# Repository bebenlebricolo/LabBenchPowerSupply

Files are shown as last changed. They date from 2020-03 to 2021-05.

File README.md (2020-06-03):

# LabBenchPowerSupply
A Diy lab bench power supply, made as simple as possible, from an Arduino Nano and generic discrete parts

## Motivation(s)
### A complete design, built from the ground up, for everyone
The main goal of this project is indeed to build a bench power supply, but I really wanted to provide a complete project including all the electronical design, mechanical design and software design that goes with it.

### Keep it simple, and as cheap as possible!
#### The Electronical side of the force
This project is built around simple electronic devices/parts which we could find in almost any electronic store with a decent collection of parts. The parts were chosen with 2 main things in mind :
* **They need to be cheap !** If cheaper does not always correlates with better, cheap parts are often related to products that have been around for a long time and have demonstrated their capabilities more times than we can ever count them.
* **They need to fulfill their task without compromises** : the chosen parts shall largely fit the requirements of power, size, etc.. This is essentially a safety requirement, there is no usage for us here to size the parts so close to the requirements we don't have any error margin left.
* **They need to be available** almost everywhere, and not only restricted to some obscure parts of the world. If not, they need to have a compatible part we can rely on.
* **They need to be well-documented** : who wants to use parts with poor datasheets? This requirement is pretty standard anyway, however having a good datasheet allows a better understanding of its internal mechanics, and sometimes even provides equivalent parts/complementary parts.
* Ideally, they should be still in production. Just because it seems better to have recent parts ...

### Keep it open!
As a final motivation, I want the firmware to be as open as possible, I hope by doing so that anyone with a little coding experience can tweak the firmware to more specifically meet his/her needs.

## Built around an Arduino Nano
This choice was made for several reason, the biggest one being that Arduino has built a gigantic ecosystel around their product, that almost every hobbyist interested into electronic will have lying around, somewhere, lying under a pile of other projects.

In the other hand, the cheapest Arduinos are built around Atmel's 8 bit chips, which are quite simple to work with. Transitionning from Arduino's IDE to a more software-oriented workflow is relatively easy, using the right tools. We can even seamlessly integrate a firmware which is built completely out of the Arduino world within an Arduino, without having to use any of the Arduino tools

*Note: working with Arduino tools such as Arduino IDE is totally fine and provides a super fun experience for small projects or when learning embedded systems, my point here is simply to emphasize on the transition between the Arduino world, to the "my toolchain and that's all" world*

Also, despite using an Arduino as the "brain" of this project, I also wanted to decouple the software from any Arduino-based code, because I thougth it was a good occasion to show how "simple" it could be to directly target the chip, not using any framework to hide any detail.

This is the reason why I reimplemented all the necessary drivers to interact with the peripherals of the Atmega328P, and to some extent, tried to make them compatible with most of the cheap avr cores that we could find for a handful of dollars/euros/whatever.

# Electronical design
The Electonical design of this project is entirely made using KiCAD - which I love - and I wanted a rather simple circuit, built around generic parts.

## Goals
Here is a list of the features I wanted to integrate within this project :

### Basic requirements
* Standalone powersupply, using the mains power source as its primary power source
* Does not require any extreme soldering skills : most, if not all of the components shall be through-holes ones
* Outputs a decent wattage (about 10 Amps / 12 Volts DC => depends on the components one will choose )
* Easy to tune with few interactions needed
* User interface such as an LCD screen, cheap and neat!
* Voltage and current regulations
* Allow to connect/disconnect the load using a button/lever switch

### Safety features
* Low voltages only : I want this project to only output voltages that are well below the hazardous range. I plan to output a maximum 16 Volts
* Features Thermal protection : thermal sensor coupled with a thermal regulation system (variable powered fans shall be used)
* Overcurrent protection (maybe using a relay connected to 100% hardware circuit)

### Miscellaneous
* Banana plugs output connectors, for ease of use
* Eventually, XT connectors interface (because the connector provide a polar interface which prevents reversing polarities, more handy)
* Simple buttons interface to drive the powersupply
* Would be nice to have some profiles registered in the system, such as 10 memories with various settings

# Software design
As succintly explained in the header of this readme, I want a simple software to run on this machine. However, there are some critical aspects to be kept in mind here, such as the several safety features which have to be implemented cleanly.
This brought me to redevelop all the drivers only using the datasheet of Atmel's (now Microchip) Atmega328P as a reference.

## Testing
While developping the software for this project, I needed a way to consolidate my developments as it is not really trivial to debug the code once it is embedded on the device. That is why I am writing my tests in parallel to project development, which allows to detect errors earlier and make sure the logic is right (this is what testing is all about, after all!).

### Approach for drivers testing
#### Using GoogleTest testing framework
Testing an application is rather easy to do when developping application software as it is rather simple to substitute components, because already abstracted.
However, it is a quite different topic when working on drivers, because they are completely dependent of the hardware they rely on. This is why I had to use a dependency injection approach, substituting the internal peripheral's interface register by stubbed ones, allowing me to 'simulate' the actual behavior of the peripheral.

#### Using simulators, such as simavr!
The bad thing is that even when trying to mimic the peripheral registers, sometimes we can make mistakes and all tests are passing, but the code does not run well on the real target. Actually, reproducing the hardware's behavior in test cases is subject to your own assumptions and understanding about the hardware, it is rather easy to get out of sync with it.

One solution is to use simulators, such the one embedded wihtin AtmelStudio7 or using simavr on Linux.
Despite not being 100% accurate, they both offer really good starting points when it comes to simulating the targeted avr core, I discovered many mistakes in the code like this, despite my tests being all passing.

## Drivers
The main goal here is to implement drivers whose only role is to abstract the hardware's peripheral details. No less, and certainly no more. As a result, they may need more high level components which will handle the low-levels details instead of direclty calling it from application software.

### Example : timers
For instance, all the timers APIs are matching the underlying hardware, exposing things such as their running mode (fast_pwm generator, phase_correct_pwm_generator, Clear Timer on Compare match, Output Compare modes, Interrupt-based, non interrupt-based, etc).

Their purpose is to provide a uniform interface, that you can interact with either using unitary calls (such as timer_8_bit_set_interrupt_enable()) or complete configuration calls such as timer_8_bit_init() which needs an explicit configuration object.

So their interface is quite complete (and tested), but we still need some more specialized modules to use them.

To continue with the Timer example, let's think about a PWM module : let's say I want a PWM module, which configures one of the available timer to produce an accurate, hardware-based pwm signal.
This module will one of the 8 bit timer, and perform all the necessary driver manipulation to achieve its goal.

We could then have something like this :
```C
/* Error handling should be done in between calls but is eluded for clarity */
pwm_error_t ret = PWM_ERROR_OK;
ret = pwm_init(gpio_structure);
ret = pwm_set_frequency(150'000);
ret = pwm_set_duty_cycle(75);
ret = pwm_start();
```

All the drivers are built using this approach : a driver is no more and no less than a driver. This leaves the possibility to fine-tune the hardware as well as building high level modules, taylored for each given purposes.

Last but not least, as the drivers expose a fairly complete set of accessors and functions that could be used at any moment, it could represent a substantial amount of unused functions. This is why they are built with the `-flto` flag as well as the `-ffunction-sections` and `-Wl,--gc-sections` flags, which allow respectively :
* `-flto` : tells the linker to perform a link-time optimisation pass (trims unused functions for instance)
* `-ffunction-sections` : place each functions in its own section
* `-Wl,--gc-sections` : garbage-collects unused sections

Those flags are defined within the `avr-gcc-toolchain.cmake` file, which also defines a bunch of parameters to cross-compile the project onto avr targets.

# Required tools to build on Linux :
## Building application firmware
### Avr gcc toolchain and ABI
* gcc (version >= 8.3.0)
* gcc-avr (version >= 8.3.0)
* avr-libc
* binutils-avr

*Note : at the moment, ubuntu repositories does not provide an up-to-date version of avr-gcc toolchain(5.4.0, which does not support -lto flag). You can either build avr-gcc from sources to use a more version of gcc (like 9.3.0) or retrieve an existing package if it has been compiled by someone before. This note will hopefully disapear as I have already done this step myself, I will need to build a consistent package for it though*

### Cmake tools
* Cmake (version >= 3.0)

## Building tests
To build the tests, make sure you have `libgtest-dev`installed on your machine
### Ubuntu 20.04
* Google tests libraries and binaries
    * libgtest-dv
    * googletest

* GCC tools :
    * build-essentials or
    * gcc (version >= 8.3.0)

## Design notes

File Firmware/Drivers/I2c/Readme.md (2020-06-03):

# I2C Driver for Atmega328xx chip (and other AVR cores)
This I2C driver was implemented as part of the LabBenchPowerSupply project, in its very early development stages.
It provides a simple interface to configure and use the Atmel's/Microchip's Two Wire Interface peripheral embedded in most of their AVR core,
in fully asynchronous operation mode.

## What's provided with it
### Fully asynchronous operating mode
This driver could be used **with** or **without** hardware-based interrupt (twi interrupt vector), leaving full control over the software stack and providing the ability to configure and use several TWI peripheral using a **single driver**.
For instance, this could be useful when working with the Atmega328PB which embeds several TWI, all wired to the same interrupt (twi_vect).
By design, this driver is not blocking : this means the CPU is free to continue its work instead of wasting cycles waiting for TWI hardware to complete its task. 

### Simple interface, full control over configuration
As this driver could be relatively complex, it was essential to reduce the amount of work put into the device configuration to its bare minimum.
This driver then provides a default configuration, that one may use as a starting point to configure the driver.
On the other hand, full control might be required at some point, and one may not want to fully reconfigure the whole device when a single parameter can just be changed. This is easily done using the **unitary parameter API** offered with the driver : it allows to get/set a single parameter of the device.
However, be carefull when using those ones : operation is only permitted while TWI peripheral is not processing (i.e. TWINT flag is set to 1).

### Simple operations as master, or slave
This driver provides two functions to handle reading and writing to a slave, **i2c_write** and **i2c_read**. They both configure the driver as a master, and sets relevant data in TWI registers. Then, the i2c_process() function or interrupt will be used to handle the transaction.
Also, the slave interface of this driver allows to define an I2C exposed data interface and uses a dedicated function pointer used to handle incoming bytes.
This callback function needs to be overridden by application software, and is called whenever the devices is addressed as a slave on the I2C bus.

### Fully tested interface
This driver comes with a load of tests (written with google Tests framework) which allow to put the device into several scenarios and see how it's behaving.
Although testing the unitary interface is pretty trivial, testing the actual master or slaves operating modes requires some more work.
As a consequence, I've written a rather complete I2C bus simulator which registers virtual I2C devices and exchanges data between them.
This is why I had to write a simulator for the TWI peripheral (which is called **twi_hardware_stub**), the I2c bus simulator itself, called **I2cBusSimulator** (and which is the only written in C++, because why not!), and another virtual I2C device which is called **i2c_fake_device**.

This design allows to test the driver under many scenarios, as a master, transmitting mode, master receveiver, slave transmitter, slave receiver, and even mixing all modes together in a sequence to assert that the driver handles mode transitions just fine. 

# How to use the driver
Note that the examples below are only here to depict how this driver works and does not reflect any application firmware design.
For more details about the inner mechanics, a good look at **i2c_driver_tests.cpp** located in Tests/ might give a more detailed picture on how the driver might be used.

## Initialisation
First, you will need to configure it in the initialisation step:

```C
#include "i2c.h"
...
...
// In application code : (for instance in a function called init_transmission() =
i2c_config_t config;
i2c_error_t ret = i2c_get_default_config(&config);
// Check that everything's fine
if (I2C_ERROR_OK != ret)
{
    // Handle error here
}

// Initialise the handle with the right data :
// Note : step of using pointer to memory might appear weird, or even a bad idea.
// However, this is the key to handle several TWI devices as well as enabling Dependency Injection for testing purposes
// Furthermore, those registers are not accessed very often (we are not accessing them like we would if those were GPIO registers with precise PWM timing requirements!)
config.handle.TWCR = &TWCR;
config.handle.TWBR = &TWBR;
config.handle.TWSR = &TWSR;
config.handle.TWDR = &TWDR;
config.handle.TWAR = &TWAR;
config.handle.TWAMR = &TWAMR;

// Set whatever parameter you want in config object
config.slave_address = 0x34;

// Assuming this is the only device used by your application firmware
// Note : to be able to do this, application firmware shall provide a "config.h" file which defines the I2C_DEVICES_COUNT macro like so : 
// #define I2C_DEVICES_COUNT (1U)
ret = i2c_init(0U, &config);
if (I2C_ERROR_OK != ret)
{
    // Handle error here
}
i2c_state_t state;
ret = i2c_get_state(0U, &state);
if (I2C_ERROR_OK != ret || I2C_STATE_READY != state)
{
    // Handle error here
}
```

## Starting a transmission as master (for instance, a write transmission)

```C
// Within some application code :

...
...

// Define a buffer with enough space to carry all required data
uint8_t buffer[MULTI_BYTES_ARRAY_LEN + 1] = {0};

// First byte of the buffer contains the operation code / command which will be interpreted by targeted device
buffer[0] = TARGET_DEVICE_COMMAND_MESSAGE;

// Fill in the message ...
snprintf((char *) (buffer + 1), MULTI_BYTES_ARRAY_LEN, "Some message to be written");

// If you want to use interrupts :
// sei();

// Device is in its READY state, time to ask it to start a write transaction
ret = i2c_write(0U, 0x23, buffer, 25, 0U);
if (I2C_ERROR_OK != ret)
{
    // Handle error here
}

``` 

## Processing data (if not interrupt based)

```C
// If NOT using interrupts, you will have to call :
i2c_process(0U);
// Otherwise, interrupt service routine will do that for you automatically

// Polling the device state to know if the transaction has completed :
i2c_state_t state;
ret = i2c_get_state(0U, &state);
if (I2C_ERROR_OK != ret)
{
    // Handle error here
}

if (I2C_STATE_READY == state)
{
    // Proceed with next operation
}

```

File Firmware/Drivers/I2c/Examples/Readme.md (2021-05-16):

# I2C End to End testing firmwares
Those fake firmwares were written in the aim to help optimizing/debugging I2C drivers.
They run on real chips, so we'll need real working devices (for instance Arduino Uno(s) or Arduino nano(s)).
As those firmwares try to test the I2C driver, the only dependency requirement shall be restricted to that driver only.

# Scenarios
We'll need to test several configurations such as :
* A master I2C device writing to a slave device
* A master I2C device reading from a slave device without opcode (direct read)
* A master I2C device reading from a slave device with opcode (an I2C write is performed first)
* A master I2C device writing data to a slave device then reading data back from it

# How to build them
Each fake firmware works independently of any other CMake project, so in order to build any of them, you'll need to go into its directory (for instance `master_firmware`) and type in those commands (if you are running Linux):
```bash
mkdir build
cd build
cmake ../
make
```
And you're done compiling the firmware.
Repeat the same procedure for the other one, and that's pretty much it !

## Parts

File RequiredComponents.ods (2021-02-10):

Component name | Manufacturer | Description | Link to part | Unit price TTC (€)
Power components
THS10R10J | TE Connectivity | Resistance 0,1 Ohms 10 Watts | rs-online (https://fr.rs-online.com/web/p/resistances-de-puissance/7547622/)
IRFZ14PBF | Vishay | Mosfet N 45W 10A | https://fr.rs-online.com/web/p/transistors-mosfet/5411685/
STP60NF06L | STMicroelectonics | Mosfet N 60A 60V 110W | https://fr.rs-online.com/web/p/transistors-mosfet/4857816/
IRF5305PBF | Infineon | Mosfet P 31A 55V TO-220 110W | https://fr.rs-online.com/web/p/transistors-mosfet/5411736/ | 1.44
IRFU5305PBF | Infineon | Mosfet P 31A 55V TO-251 110W | https://fr.rs-online.com/web/p/transistors-mosfet/5429951/ | 1.06
IRF5210PBF | Infineon | Mosfet P 40A 100V TO-220 200W | https://fr.rs-online.com/web/p/transistors-mosfet/5411720/ | 2.62
DPO-10-100 | RS PRO | Inductance 100µH 10A | https://fr.rs-online.com/web/p/inductances-traversantes/1048448/
SDT10A100CT | DiodesZetex | 3 leads Shottky diodes, 10A, 100V, common cathode | https://fr.rs-online.com/web/p/diodes-de-redressement-et-schottky/1464841/
10A04-T | DiodesZetex | Commutation regular silicon diode, 10A, 400V | https://fr.rs-online.com/web/p/diodes-de-commutation/7512705P/
671-9129 | RS PRO | 2x 115/25V transformer, 80 VA | https://fr.rs-online.com/web/p/transformateurs-toriques/6719129/
Capacitors
RS477-50V-RL13x21 | RS PRO | Electrolytic capacitor 470µF/50V | https://fr.rs-online.com/web/p/condensateurs-aluminium/7111479/
711-1510 | RS PRO | Electrolytic capacitor 2200µF/50V | https://fr.rs-online.com/web/p/condensateurs-aluminium/7111510/
X2 capacitor | Kemet | 150nF +-20 %, 310Vac, 630V dc, X2 capacitor | https://fr.rs-online.com/web/p/condensateurs-polypropylene/1262221/
Y2 capacitor | Kemet | 22nF +-20 %, 300 Vac, 1kV dc | https://fr.rs-online.com/web/p/condensateurs-polypropylene/1650068/
Thermal management
Heatsink TO-220 |  | Heatsink 34x30x12mm | https://www.aliexpress.com/item/32834691585.html
FA-T220-38E | Ohmite | Heatsink 41.6x25x38.1mm 3.8K/W | https://fr.rs-online.com/web/p/dissipateurs-de-chaleur/8934945/
FA-T220-51E | Ohmite | Heatsink 41.6x25x50.8mm 3.4K/W | https://fr.rs-online.com/web/p/dissipateurs-de-chaleur/8934948/
80x80mm Fan | Cikuso | 80x80mm 12V, 0,18A brushless | https://fr.aliexpress.com/item/4000090406540.html
40x40 Fan Ball bearings | JIESAMMY | 40x40mm (12V 0,1A ; 24V ; 0,08A, 1,92W) ball bearings | https://fr.aliexpress.com/item/33012020984.html
80x80mm 24V Fan | Delta Electronics Inc. | 80x80mm 24V 0,12A ball bearings | https://fr.aliexpress.com/item/32837253236.html
Connectors
Jst 2 poles wire + connector | Jst | Wires + connectors (male/female) | https://www.aliexpress.com/item/32822128879.html
Terminal 2 poles |  | 2 poles, 10A, with screws | https://www.aliexpress.com/item/33018729203.html
Terminal 2 poles |  | 2 poles, 20A, with screws | https://www.aliexpress.com/item/32961019373.html
Miscellaneous
SRD-12VDC-SL-C |  | Relay 12V ; 10A / 110V ; single channel, Normally Open | https://fr.aliexpress.com/item/32849311096.html
Switch Dpst |  | 6A, 2 poles On-On | https://fr.aliexpress.com/item/33022608497.html
1mm copper wire | Block | 1mm, 11m, enamled copper wire (AWG 18) ; up to 19A continuous | https://fr.rs-online.com/web/p/fils-de-cuivre/7790713/

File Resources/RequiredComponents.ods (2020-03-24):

Component name | Manufacturer | Description | Link to part
THS10R10J | TE Connectivity | Resistance 0,1 Ohms 10 Watts | https://fr.rs-online.com/web/p/resistances-de-puissance/7547622/
IRFZ14PBF | Vishay | Mosfet N 45W 10A | https://fr.rs-online.com/web/p/transistors-mosfet/5411685/
DPO-10-100 | RS PRO | Inductance 100µH 10A | https://fr.rs-online.com/web/p/inductances-traversantes/1048448/
RS477-50V-RL13x21 | RS PRO | Electrolytic capacitor 470µF/50V
RS228-50V-RL18x36 | RS PRO | Electrolytic capacitor 2200µF/50V
SDT10A100CT | DiodesZetex | 3 leads Shottky diodes, 10A, 100V, common cathode
10A04-T | DiodesZetex | Commutation regular silicon diode, 10A, 400V

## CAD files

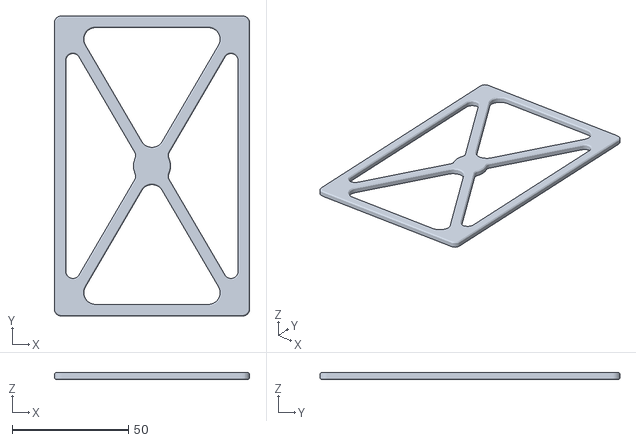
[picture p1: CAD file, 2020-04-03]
BoardDesign/Mechanical/StickingBase.stl
84.0 x 129.0 x 3.00

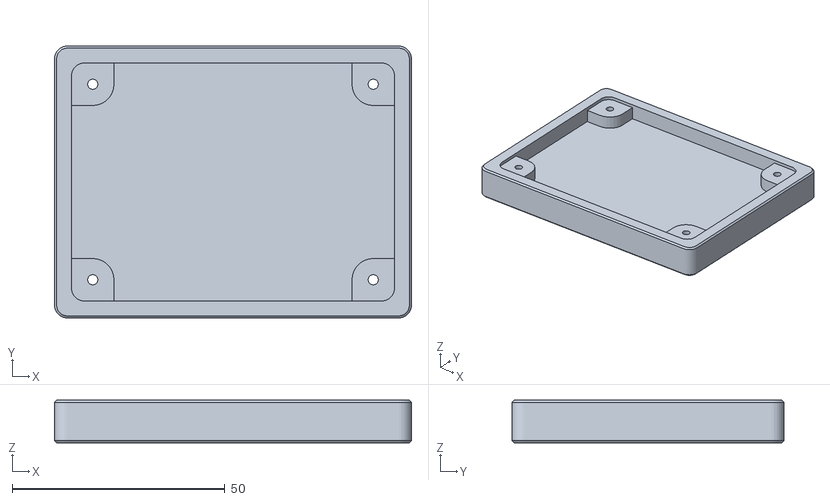
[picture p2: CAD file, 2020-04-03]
BoardDesign/Mechanical/MountBaseThick.stl
84.0 x 64.0 x 10.0

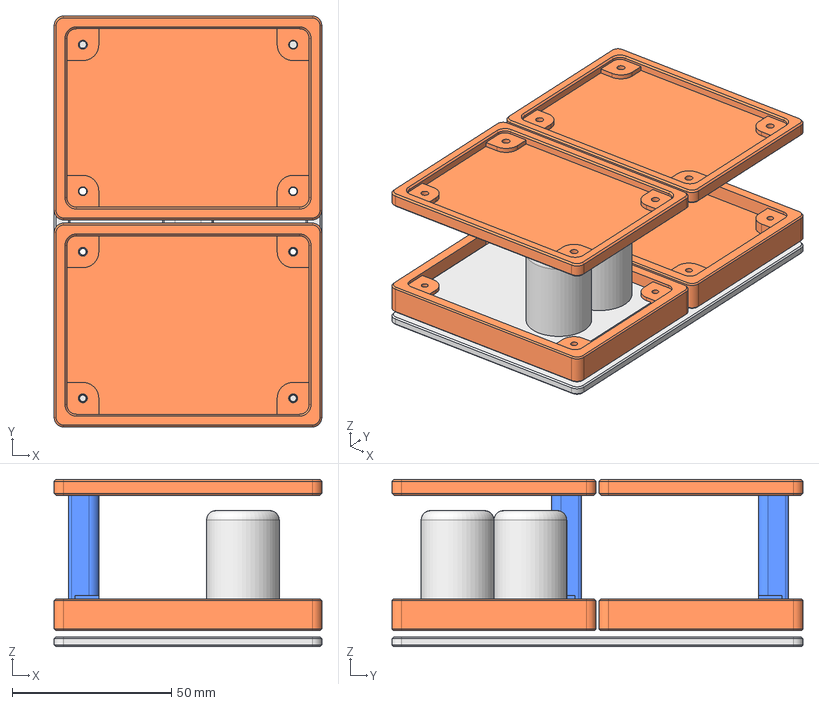
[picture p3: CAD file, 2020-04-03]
BoardDesign/Mechanical/Proto1_BoardMount.FCStd
84.0 x 129.0 x 52.5 mm
Mount base slim
BoardMockup
Supports
Mount base thick
StickingBase
Supports001
Mount base thick001
Mount base slim001
BoardMockup001

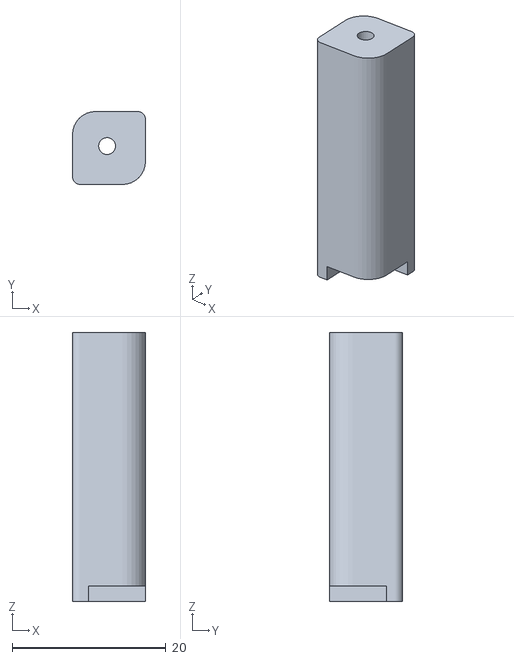
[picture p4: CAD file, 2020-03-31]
BoardDesign/Mechanical/Supports.stl
9.50 x 9.50 x 35.0

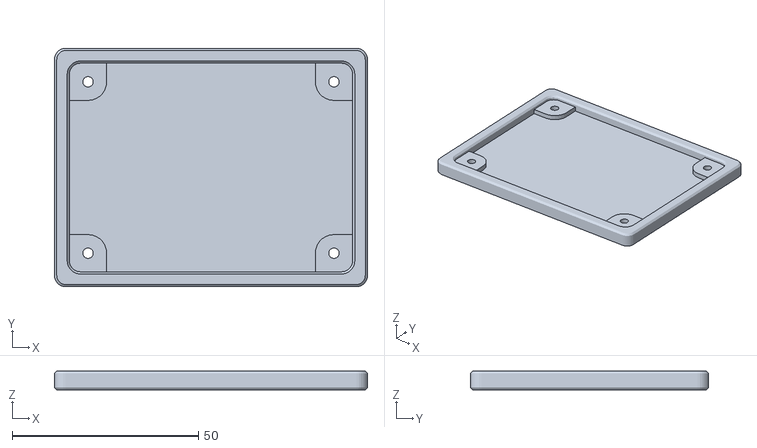
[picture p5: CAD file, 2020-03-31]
BoardDesign/Mechanical/MountBaseSlim.stl
84.0 x 64.0 x 5.00

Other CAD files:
BoardDesign/Mechanical/MountBase.stl

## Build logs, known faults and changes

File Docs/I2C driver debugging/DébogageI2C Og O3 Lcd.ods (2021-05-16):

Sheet: Agrégées
Boot Og | Boot O3 |  | Steady O3 | Steady Og
0x3C | 0x3C | 1 |  | 0x3D | 0
0x38 | 0x38 | 1 |  | 0x39 | 0
0x3C | 0x3C | 1 |  | 0xCC | 1
0x38 | 0x38 | 1 |  | 0xC8 | 1
0x3C | 0x3C | 1 |  | 0x4C | 1
0x38 | 0x38 | 1 |  | 0x48 | 1
0x2C | 0x2C | 1 |  | 0x3D | 1
0x28 | 0x28 | 1 |  | 0x39 | 1
0x2C | 0x2C | 1 |  | 0x1D | 0
0x28 | 0x28 | 1 |  | 0x19 | 0
0x8C | 0x8C | 1 |  | 0x3D | 1
0x88 | 0x88 | 1 |  | 0x39 | 1
0x0C | 0x0C | 1 |  | 0x0D | 1
0x08 | 0x08 | 1 |  | 0x09 | 1
0xBC | 0xBC | 1 |  | 0x3D | 0
0xB8 | 0xB8 | 1 |  | 0x39 | 0
0x0C | 0x0C | 1 |  | 0x4D | 0
0x08 | 0x08 | 1 |  | 0x49 | 0
0x1C | 0x1C | 1 |  | 0xCC | 1
0x18 | 0x18 | 1 |  | 0xC8 | 1
0x0C | 0x0C | 1 |  | 0x4C | 1
0x08 | 0x08 | 1 |  | 0x48 | 1
0x6C | 0x6C | 1 |  | 0x3D | 1
0x68 | 0x68 | 1 |  | 0x39 | 1
0x0C | 0x0C | 1 |  | 0x1D | 0
0x08 | 0x08 | 1 |  | 0x19 | 0
0xFC | 0xFC | 1 |  | 0x3D | 1
0xF8 | 0xF8 | 1 |  | 0x39 | 1
0x8C | 0x8C | 1 |  | 0x0D | 1
0x88 | 0x88 | 1 |  | 0x09 | 1
0x0C | 0x0C | 1 |  | 0x3D | 0
0x08 | 0x08 | 1 |  | 0x39 | 0
0x4D | 0x4D | 1 |  | 0x5D | 0
0x49 | 0x49 | 1 |  | 0x59 | 0
0x8D | 0x8D | 1 |  | 0xCC | 1
0x89 | 0x89 | 1 |  | 0xC8 | 1
0x6D | 0x6D | 1 |  | 0x4C | 1
0x69 | 0x69 | 1 |  | 0x48 | 1
0x5D | 0x5D | 1 |  | 0x3D | 1
0x59 | 0x59 | 1 |  | 0x39 | 1
0x6D | 0x6D | 1 |  | 0x1D | 0
0x69 | 0x69 | 1 |  | 0x19 | 0
0xCD | 0xCD | 1 |  | 0x3D | 1
0xC9 | 0xC9 | 1 |  | 0x39 | 1
0x6D | 0x6D | 1 |  | 0x0D | 1
0x69 | 0x69 | 1 |  | 0x09 | 1
0xCD | 0xCD | 1 |  | 0x3D | 0
0xC9 | 0xC9 | 1 |  | 0x39 | 0
0x6D | 0x6D | 1 |  | 0x6D | 0
0x69 | 0x69 | 1 |  | 0x69 | 0
 |  |  |  | 0xCC | 1
 |  |  |  | 0xC8 | 1
 |  |  |  | 0x4C | 1
 |  |  |  | 0x48 | 1
 |  |  |  | 0x3D | 1
 |  |  |  | 0x39 | 1
 |  |  |  | 0x1D | 0
 |  |  |  | 0x19 | 0
 |  |  |  | 0x3D | 1
 |  |  |  | 0x39 | 1
 |  |  |  | 0x0D | 1
 |  |  |  | 0x09 | 1
 |  |  |  | 0x3D | 0
 |  |  |  | 0x39 | 0
 |  |  |  | 0x7D | 0
 |  |  |  | 0x79 | 0
 |  |  | 0xCC | 0xCC | 1
 |  |  | 0xC8 | 0xC8 | 1
 |  |  | 0x4C | 0x4C | 1
 |  |  | 0x48 | 0x48 | 1
 |  |  | 0x3D | 0x3D | 1
 |  |  | 0x39 | 0x39 | 1
 |  |  | 0x3D | 0x1D | 0
 |  |  | 0x39 | 0x19 | 0
 |  |  | 0x3D | 0x3D | 1
 |  |  | 0x39 | 0x39 | 1
 |  |  | 0x0D | 0x0D | 1
 |  |  | 0x09 | 0x09 | 1
 |  |  | 0x2D | 0x3D | 0
 |  |  | 0x29 | 0x39 | 0
 |  |  | 0x0D | 0x8D | 0
 |  |  | 0x09 | 0x89 | 0
 |  |  | 0xCC | 0xCC | 1
 |  |  | 0xC8 | 0xC8 | 1
 |  |  | 0x4C | 0x4C | 1
 |  |  | 0x48 | 0x48 | 1
 |  |  | 0x3D | 0x3D | 1
 |  |  | 0x39 | 0x39 | 1
 |  |  | 0x3D | 0x1D | 0
 |  |  | 0x39 | 0x19 | 0
 |  |  | 0x3D | 0x3D | 1
 |  |  | 0x39 | 0x39 | 1
 |  |  | 0x1D | 0x0D | 0
 |  |  | 0x19 | 0x09 | 0
 |  |  | 0x2D | 0x3D | 0
 |  |  | 0x29 | 0x39 | 0
 |  |  | 0x0D | 0x9D | 0
 |  |  | 0x09 | 0x99 | 0
 |  |  | 0xCC | 0xCC | 1
 |  |  | 0xC8 | 0xC8 | 1
 |  |  | 0x4C | 0x4C | 1
 |  |  | 0x48 | 0x48 | 1
 |  |  | 0x3D | 0x3D | 1
 |  |  | 0x39 | 0x39 | 1
 |  |  | 0x3D | 0x1D | 0
 |  |  | 0x39 | 0x19 | 0
 |  |  | 0x3D | 0x3D | 1
 |  |  | 0x39 | 0x39 | 1
 |  |  | 0x2D | 0x1D | 0
 |  |  | 0x29 | 0x19 | 0
 |  |  | 0x2D | 0x3D | 0
 |  |  | 0x29 | 0x39 | 0
 |  |  | 0x0D | 0x0D | 1
 |  |  | 0x09 | 0x09 | 1
 |  |  | 0xCC | 0xCC | 1
 |  |  | 0xC8 | 0xC8 | 1
 |  |  | 0x4C | 0x4C | 1
 |  |  | 0x48 | 0x48 | 1
 |  |  | 0x3D | 0x3D | 1
 |  |  | 0x39 | 0x39 | 1
 |  |  | 0x3D | 0x1D | 0
 |  |  | 0x39 | 0x19 | 0
 |  |  | 0x3D | 0x3D | 1
 |  |  | 0x39 | 0x39 | 1
 |  |  | 0x3D | 0x1D | 0
 |  |  | 0x39 | 0x19 | 0
 |  |  | 0x2D | 0x3D | 0
 |  |  | 0x29 | 0x39 | 0
 |  |  | 0x0D | 0x1D | 0
 |  |  | 0x09 | 0x19 | 0
 |  |  | 0xCC | 0xCC | 1
 |  |  | 0xC8 | 0xC8 | 1
 |  |  | 0x4C | 0x4C | 1
 |  |  | 0x48 | 0x48 | 1
 |  |  | 0x3D | 0x3D | 1
 |  |  | 0x39 | 0x39 | 1
 |  |  | 0x3D | 0x1D | 0
 |  |  | 0x39 | 0x19 | 0
 |  |  | 0x3D | 0x3D | 1
 |  |  | 0x39 | 0x39 | 1
 |  |  | 0x4D | 0x1D | 0
 |  |  | 0x49 | 0x19 | 0
 |  |  | 0x2D | 0x3D | 0
 |  |  | 0x29 | 0x39 | 0
 |  |  | 0x0D | 0x2D | 0
 |  |  | 0x09 | 0x29 | 0
 |  |  | 0xCC | 0xCC | 1
 |  |  | 0xC8 | 0xC8 | 1
 |  |  | 0x4C | 0x4C | 1
 |  |  | 0x48 | 0x48 | 1
 |  |  | 0x3D | 0x3D | 1
 |  |  | 0x39 | 0x39 | 1
 |  |  | 0x3D | 0x1D | 0
 |  |  | 0x39 | 0x19 | 0
 |  |  | 0x3D | 0x3D | 1
 |  |  | 0x39 | 0x39 | 1
 |  |  | 0x5D | 0x1D | 0
 |  |  | 0x59 | 0x19 | 0
 |  |  | 0x2D | 0x3D | 0
 |  |  | 0x29 | 0x39 | 0
 |  |  | 0x0D | 0x3D | 0
 |  |  | 0x09 | 0x39 | 0
 |  |  | 0xCC | 0xCC | 1
 |  |  | 0xC8 | 0xC8 | 1
 |  |  | 0x4C | 0x4C | 1
 |  |  | 0x48 | 0x48 | 1
 |  |  | 0x3D | 0x3D | 1
 |  |  | 0x39 | 0x39 | 1
 |  |  | 0x3D | 0x1D | 0
 |  |  | 0x39 | 0x19 | 0
 |  |  | 0x3D | 0x3D | 1
 |  |  | 0x39 | 0x39 | 1
 |  |  | 0x6D | 0x1D | 0 |  | 00000000
 |  |  | 0x69 | 0x19 | 0 | 69 | 01101001
 |  |  | 0x2D | 0x3D | 0 | 2D | Err :502
 |  |  | 0x29 | 0x39 | 0 | 29 | 00101001
 |  |  | 0x0D | 0x4D | 0 | 0D | Err :502
 |  |  | 0x09 | 0x49 | 0 | 9 | 00001001
 |  |  | 0xCC | 0xCC | 1 | CC | Err :502
 |  |  | 0xC8 | 0xC8 | 1 | C8 | Err :502
 |  |  | 0x4C | 0x4C | 1 | 4C | Err :502
 |  |  | 0x48 | 0x48 | 1 | 48 | 01001000
 |  |  | 0x3D | 0x3D | 1 | 3D | Err :502
 |  |  | 0x39 | 0x39 | 1 | 39 | 00111001
 |  |  | 0x3D | 0x1D | 0 | 3D | Err :502
 |  |  | 0x39 | 0x19 | 0 | 39 | 00111001
 |  |  | 0x3D | 0x3D | 1 | 3D | Err :502
 |  |  | 0x39 | 0x39 | 1 | 39 | 00111001
 |  |  | 0x7D | 0x1D | 0 | 7D | Err :502
 |  |  | 0x79 | 0x19 | 0 | 79 | 01111001
 |  |  | 0x2D | 0x3D | 0 | 2D | Err :502
 |  |  | 0x29 | 0x39 | 0 | 29 | 00101001
 |  |  | 0x0D | 0x5D | 0 | 0D | Err :502
 |  |  | 0x09 | 0x59 | 0 | 9 | 00001001
 |  |  | 0xCC | 0xCC | 1 | CC | Err :502
 |  |  | 0xC8 | 0xC8 | 1 | C8 | Err :502
 |  |  | 0x4C | 0x4C | 1 | 4C | Err :502
 |  |  | 0x48 | 0x48 | 1 | 48 | 01001000
 |  |  | 0x3D | 0x3D | 1 | 3D | Err :502
 |  |  | 0x39 | 0x39 | 1 | 39 | 00111001
 |  |  | 0x3D | 0x1D | 0 | 3D | Err :502
 |  |  | 0x39 | 0x19 | 0 | 39 | 00111001
 |  |  | 0x3D | 0x3D | 1 | 3D | Err :502
 |  |  | 0x39 | 0x39 | 1 | 39 | 00111001
 |  |  | 0x8D | 0x1D | 0 | 8D | Err :502
 |  |  | 0x89 | 0x19 | 0 | 89 | 10001001
 |  |  | 0x2D | 0x3D | 0 | 2D | Err :502
 |  |  | 0x29 | 0x39 | 0 | 29 | 00101001
 |  |  | 0x0D | 0x6D | 0 | 0D | Err :502
 |  |  | 0x09 | 0x69 | 0 | 9 | 00001001
 |  |  | 0xCC | 0xCC | 1 | CC | Err :502
 |  |  | 0xC8 | 0xC8 | 1 | C8 | Err :502
 |  |  | 0x4C | 0x4C | 1 | 4C | Err :502
 |  |  | 0x48 | 0x48 | 1 | 48 | 01001000
 |  |  | 0x3D | 0x3D | 1 | 3D | Err :502
 |  |  | 0x39 | 0x39 | 1 | 39 | 00111001
 |  |  | 0x3D | 0x1D | 0 | 3D | Err :502
 |  |  | 0x39 | 0x19 | 0 | 39 | 00111001
 |  |  | 0x3D | 0x3D | 1 | 3D | Err :502
 |  |  | 0x39 | 0x39 | 1 | 39 | 00111001
 |  |  | 0x9D | 0x1D | 0 | 9D | Err :502
 |  |  | 0x99 | 0x19 | 0 | 99 | 10011001
 |  |  | 0x2D | 0x3D | 0 | 2D | Err :502
 |  |  | 0x29 | 0x39 | 0 | 29 | 00101001
 |  |  | 0x0D | 0x7D | 0 | 0D | Err :502
 |  |  | 0x09 | 0x79 | 0 | 9 | 00001001
 |  |  | 0xCC | 0xCC | 1 | CC | Err :502
 |  |  | 0xC8 | 0xC8 | 1 | C8 | Err :502
 |  |  | 0x4C | 0x4C | 1 | 4C | Err :502
 |  |  | 0x48 | 0x48 | 1 | 48 | 01001000
 |  |  | 0x3D | 0x3D | 1 | 3D | Err :502
 |  |  | 0x39 | 0x39 | 1 | 39 | 00111001
 |  |  | 0x4D | 0x1D | 0 | 4D | Err :502
 |  |  | 0x49 | 0x19 | 0 | 49 | 01001001
 |  |  | 0x3D | 0x3D | 1 | 3D | Err :502
 |  |  | 0x39 | 0x39 | 1 | 39 | 00111001
 |  |  | 0x0D | 0x1D | 0 | 0D | Err :502
 |  |  | 0x09 | 0x19 | 0 | 9 | 00001001
 |  |  | 0x2D | 0x3D | 0 | 2D | Err :502
 |  |  | 0x29 | 0x39 | 0 | 29 | 00101001
 |  |  | 0x0D | 0x8D | 0 | 0D | Err :502
 |  |  | 0x09 | 0x89 | 0 | 9 | 00001001
 |  |  | 0xCC | 0xCC | 1 | CC | Err :502
 |  |  | 0xC8 | 0xC8 | 1 | C8 | Err :502
 |  |  | 0x4C | 0x4C | 1 | 4C | Err :502
 |  |  | 0x48 | 0x48 | 1 | 48 | 01001000
 |  |  | 0x3D | 0x3D | 1 | 3D | Err :502
 |  |  | 0x39 | 0x39 | 1 | 39 | 00111001
 |  |  | 0x4D | 0x1D | 0 | 4D | Err :502
 |  |  | 0x49 | 0x19 | 0 | 49 | 01001001
 |  |  | 0x3D | 0x3D | 1 | 3D | Err :502
 |  |  | 0x39 | 0x39 | 1 | 39 | 00111001
 |  |  | 0x1D | 0x1D | 1 | 1D | Err :502
 |  |  | 0x19 | 0x19 | 1 | 19 | 00011001
 |  |  | 0x2D | 0x3D | 0 | 2D | Err :502
 |  |  | 0x29 | 0x39 | 0 | 29 | 00101001
 |  |  | 0x0D | 0x9D | 0 | 0D | Err :502
 |  |  | 0x09 | 0x99 | 0 | 9 | 00001001
 |  |  | 0xCC | 0xCC | 1 | CC | Err :502
 |  |  | 0xC8 | 0xC8 | 1 | C8 | Err :502
 |  |  | 0x4C | 0x4C | 1 | 4C | Err :502
 |  |  | 0x48 | 0x48 | 1 | 48 | 01001000
 |  |  | 0x3D | 0x3D | 1 | 3D | Err :502
 |  |  | 0x39 | 0x39 | 1 | 39 | 00111001
 |  |  | 0x4D | 0x1D | 0 | 4D | Err :502
 |  |  | 0x49 | 0x19 | 0 | 49 | 01001001
 |  |  | 0x3D | 0x3D | 1 | 3D | Err :502
 |  |  | 0x39 | 0x39 | 1 | 39 | 00111001
 |  |  | 0x2D | 0x2D | 1 | 2D | Err :502
 |  |  | 0x29 | 0x29 | 1 | 29 | 00101001
 |  |  | 0x2D | 0x3D | 0 | 2D | Err :502
 |  |  | 0x29 | 0x39 | 0 | 29 | 00101001
 |  |  | 0x0D | 0x0D | 1 | 0D | Err :502
 |  |  | 0x09
 |  |  | 0xCC
 |  |  | 0xC8
 |  |  | 0x4C
 |  |  | 0x48
 |  |  | 0x3D
 |  |  | 0x39
 |  |  | 0x4D
 |  |  | 0x49
 |  |  | 0x3D
 |  |  | 0x39
 |  |  | 0x3D
 |  |  | 0x39
 |  |  | 0x2D
 |  |  | 0x29
 |  |  | 0x0D
 |  |  | 0x09
 |  |  | 0xCC
 |  |  | 0xC8
 |  |  | 0x4C
 |  |  | 0x48
 |  |  | 0x3D
 |  |  | 0x39
 |  |  | 0x4D
 |  |  | 0x49
 |  |  | 0x3D
 |  |  | 0x39
 |  |  | 0x4D
 |  |  | 0x49
 |  |  | 0x2D
 |  |  | 0x29
 |  |  | 0x0D
 |  |  | 0x09
 |  |  | 0xCC
 |  |  | 0xC8
 |  |  | 0x4C
 |  |  | 0x48
 |  |  | 0x3D
 |  |  | 0x39
 |  |  | 0x4D
 |  |  | 0x49
 |  |  | 0x3D
 |  |  | 0x39
 |  |  | 0x5D
 |  |  | 0x59
 |  |  | 0x2D
 |  |  | 0x29
 |  |  | 0x0D
 |  |  | 0x09
 |  |  | 0xCC
 |  |  | 0xC8
 |  |  | 0x4C
 |  |  | 0x48
 |  |  | 0x3D
 |  |  | 0x39
 |  |  | 0x4D
 |  |  | 0x49
 |  |  | 0x3D
 |  |  | 0x39
 |  |  | 0x6D
 |  |  | 0x69
 |  |  | 0x2D
 |  |  | 0x29
 |  |  | 0x0D
 |  |  | 0x09
 |  |  | 0xCC

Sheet: DébogageI2C Og O3 Lcd
I2C | Time | Address | R/W | Data
1 | -410.900us | 0x4E | W | 0x3C
2 | 4.80000us | 0x4E | W | 0x38
3 | 4.71965ms | 0x4E | W | 0x3C
4 | 5.14140ms | 0x4E | W | 0x38
5 | 5.75745ms | 0x4E | W | 0x3C
6 | 6.17630ms | 0x4E | W | 0x38
7 | 6.62080ms | 0x4E | W | 0x2C
8 | 7.81790ms | 0x4E | W | 0x28
9 | 8.29140ms | 0x4E | W | 0x2C
10 | 9.87135ms | 0x4E | W | 0x28
11 | 10.3433ms | 0x4E | W | 0x8C
12 | 11.8440ms | 0x4E | W | 0x88
13 | 12.3270ms | 0x4E | W | 0x0C
14 | 12.9113ms | 0x4E | W | 0x08
15 | 13.3809ms | 0x4E | W | 0xBC
16 | 13.9487ms | 0x4E | W | 0xB8
17 | 14.4267ms | 0x4E | W | 0x0C
18 | 16.0086ms | 0x4E | W | 0x08
19 | 16.4766ms | 0x4E | W | 0x1C
20 | 18.0649ms | 0x4E | W | 0x18
21 | 18.5447ms | 0x4E | W | 0x0C
22 | 20.0431ms | 0x4E | W | 0x08
23 | 20.5135ms | 0x4E | W | 0x6C
24 | 21.0780ms | 0x4E | W | 0x68
25 | 21.5360ms | 0x4E | W | 0x0C
26 | 22.1576ms | 0x4E | W | 0x08
27 | 22.6063ms | 0x4E | W | 0xFC
28 | 23.1534ms | 0x4E | W | 0xF8
29 | 23.6049ms | 0x4E | W | 0x8C
30 | 24.1440ms | 0x4E | W | 0x88
31 | 24.5943ms | 0x4E | W | 0x0C
32 | 25.2248ms | 0x4E | W | 0x08
33 | 25.6865ms | 0x4E | W | 0x4D
34 | 26.1967ms | 0x4E | W | 0x49
35 | 26.6420ms | 0x4E | W | 0x8D
36 | 27.2497ms | 0x4E | W | 0x89
37 | 27.6789ms | 0x4E | W | 0x6D
38 | 28.2869ms | 0x4E | W | 0x69
39 | 28.7059ms | 0x4E | W | 0x5D
40 | 29.3204ms | 0x4E | W | 0x59
41 | 29.7503ms | 0x4E | W | 0x6D
42 | 30.3596ms | 0x4E | W | 0x69
43 | 30.8009ms | 0x4E | W | 0xCD
44 | 31.3102ms | 0x4E | W | 0xC9
45 | 31.7604ms | 0x4E | W | 0x6D
46 | 32.3495ms | 0x4E | W | 0x69
47 | 32.7875ms | 0x4E | W | 0xCD
48 | 33.4019ms | 0x4E | W | 0xC9
49 | 33.8318ms | 0x4E | W | 0x6D
50 | 34.4419ms | 0x4E | W | 0x69
51 | 34.8643ms | 0x4E | W
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

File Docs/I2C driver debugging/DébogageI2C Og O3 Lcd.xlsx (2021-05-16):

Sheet: Agrégées
Boot Og | Boot O3 |  | Steady O3 | Steady Og |  | Trimmed Og | Trimmed O3 | BitMask Og | BitMask O3 | Binconv Og | Binconv O3 | Payload Og | Payload O3 | Char Og | Char O3
0x3C | 0x3C | 1 | 0xCC | 0x3D | 0 | CC | 3D | 192 | 192 | 11000000 | 11000000 | 196 | 196 | Ä | Ä
0x38 | 0x38 | 1 | 0xC8 | 0x39 | 0 | C8 | 39 | 192 | 192 | 11000000 | 11000000 | * | *
0x3C | 0x3C | 1 | 0x4C | 0xCC | 1 | 4C | CC | 64 | 64 | 1000000 | 1000000 | * | *
0x38 | 0x38 | 1 | 0x48 | 0xC8 | 1 | 48 | C8 | 64 | 64 | 1000000 | 1000000 | * | *
0x3C | 0x3C | 1 | 0x3D | 0x4C | 1 | 3D | 4C | 48 | 48 | 110000 | 110000 | 51 | 49 | 3 | 1
0x38 | 0x38 | 1 | 0x39 | 0x48 | 1 | 39 | 48 | 48 | 48 | 110000 | 110000 | * | *
0x2C | 0x2C | 1 | 0x3D | 0x3D | 1 | 3D | 3D | 48 | 16 | 110000 | 10000 | * | *
0x28 | 0x28 | 1 | 0x39 | 0x39 | 1 | 39 | 39 | 48 | 16 | 110000 | 10000 | * | *
0x2C | 0x2C | 1 | 0x3D | 0x1D | 0 | 3D | 1D | 48 | 48 | 110000 | 110000 | 48 | 48 | 0 | 0
0x28 | 0x28 | 1 | 0x39 | 0x19 | 0 | 39 | 19 | 48 | 48 | 110000 | 110000 | * | *
0x8C | 0x8C | 1 | 0x0D | 0x3D | 1 | 0D | 3D | 0 | 0 |  |  | * | *
0x88 | 0x88 | 1 | 0x09 | 0x39 | 1 | 09 | 39 | 0 | 0 |  |  | * | *
0x0C | 0x0C | 1 | 0x2D | 0x0D | 1 | 2D | 0D | 32 | 48 | 100000 | 110000 | 32 | 52 |  | 4
0x08 | 0x08 | 1 | 0x29 | 0x09 | 1 | 29 | 09 | 32 | 48 | 100000 | 110000 | * | *
0xBC | 0xBC | 1 | 0x0D | 0x3D | 0 | 0D | 3D | 0 | 64 |  | 1000000 | * | *
0xB8 | 0xB8 | 1 | 0x09 | 0x39 | 0 | 09 | 39 | 0 | 64 |  | 1000000 | * | *
0x0C | 0x0C | 1 | 0xCC | 0x4D | 0 | CC | 4D | 192 | 192 | 11000000 | 11000000 | 196 | 196 | Ä | Ä
0x08 | 0x08 | 1 | 0xC8 | 0x49 | 0 | C8 | 49 | 192 | 192 | 11000000 | 11000000 | * | *
0x1C | 0x1C | 1 | 0x4C | 0xCC | 1 | 4C | CC | 64 | 64 | 1000000 | 1000000 | * | *
0x18 | 0x18 | 1 | 0x48 | 0xC8 | 1 | 48 | C8 | 64 | 64 | 1000000 | 1000000 | * | *
0x0C | 0x0C | 1 | 0x3D | 0x4C | 1 | 3D | 4C | 48 | 48 | 110000 | 110000 | 51 | 49 | 3 | 1
0x08 | 0x08 | 1 | 0x39 | 0x48 | 1 | 39 | 48 | 48 | 48 | 110000 | 110000 | * | *
0x6C | 0x6C | 1 | 0x3D | 0x3D | 1 | 3D | 3D | 48 | 16 | 110000 | 10000 | * | *
0x68 | 0x68 | 1 | 0x39 | 0x39 | 1 | 39 | 39 | 48 | 16 | 110000 | 10000 | * | *
0x0C | 0x0C | 1 | 0x3D | 0x1D | 0 | 3D | 1D | 48 | 48 | 110000 | 110000 | 49 | 48 | 1 | 0
0x08 | 0x08 | 1 | 0x39 | 0x19 | 0 | 39 | 19 | 48 | 48 | 110000 | 110000 | * | *
0xFC | 0xFC | 1 | 0x1D | 0x3D | 1 | 1D | 3D | 16 | 0 | 10000 |  | * | *
0xF8 | 0xF8 | 1 | 0x19 | 0x39 | 1 | 19 | 39 | 16 | 0 | 10000 |  | * | *
0x8C | 0x8C | 1 | 0x2D | 0x0D | 1 | 2D | 0D | 32 | 48 | 100000 | 110000 | 32 | 53 |  | 5
0x88 | 0x88 | 1 | 0x29 | 0x09 | 1 | 29 | 09 | 32 | 48 | 100000 | 110000 | * | *
0x0C | 0x0C | 1 | 0x0D | 0x3D | 0 | 0D | 3D | 0 | 80 |  | 1010000 | * | *
0x08 | 0x08 | 1 | 0x09 | 0x39 | 0 | 09 | 39 | 0 | 80 |  | 1010000 | * | *
0x4D | 0x4D | 1 | 0xCC | 0x5D | 0 | CC | 5D | 192 | 192 | 11000000 | 11000000 | 196 | 196 | Ä | Ä
0x49 | 0x49 | 1 | 0xC8 | 0x59 | 0 | C8 | 59 | 192 | 192 | 11000000 | 11000000 | * | *
0x8D | 0x8D | 1 | 0x4C | 0xCC | 1 | 4C | CC | 64 | 64 | 1000000 | 1000000 | * | *
0x89 | 0x89 | 1 | 0x48 | 0xC8 | 1 | 48 | C8 | 64 | 64 | 1000000 | 1000000 | * | *
0x6D | 0x6D | 1 | 0x3D | 0x4C | 1 | 3D | 4C | 48 | 48 | 110000 | 110000 | 51 | 49 | 3 | 1
0x69 | 0x69 | 1 | 0x39 | 0x48 | 1 | 39 | 48 | 48 | 48 | 110000 | 110000 | * | *
0x5D | 0x5D | 1 | 0x3D | 0x3D | 1 | 3D | 3D | 48 | 16 | 110000 | 10000 | * | *
0x59 | 0x59 | 1 | 0x39 | 0x39 | 1 | 39 | 39 | 48 | 16 | 110000 | 10000 | * | *
0x6D | 0x6D | 1 | 0x3D | 0x1D | 0 | 3D | 1D | 48 | 48 | 110000 | 110000 | 50 | 48 | 2 | 0
0x69 | 0x69 | 1 | 0x39 | 0x19 | 0 | 39 | 19 | 48 | 48 | 110000 | 110000 | * | *
0xCD | 0xCD | 1 | 0x2D | 0x3D | 1 | 2D | 3D | 32 | 0 | 100000 |  | * | *
0xC9 | 0xC9 | 1 | 0x29 | 0x39 | 1 | 29 | 39 | 32 | 0 | 100000 |  | * | *
0x6D | 0x6D | 1 | 0x2D | 0x0D | 1 | 2D | 0D | 32 | 48 | 100000 | 110000 | 32 | 54 |  | 6
0x69 | 0x69 | 1 | 0x29 | 0x09 | 1 | 29 | 09 | 32 | 48 | 100000 | 110000 | * | *
0xCD | 0xCD | 1 | 0x0D | 0x3D | 0 | 0D | 3D | 0 | 96 |  | 1100000 | * | *
0xC9 | 0xC9 | 1 | 0x09 | 0x39 | 0 | 09 | 39 | 0 | 96 |  | 1100000 | * | *
0x6D | 0x6D | 1 | 0xCC | 0x6D | 0 | CC | 6D | 192 | 192 | 11000000 | 11000000 | 196 | 196 | Ä | Ä
0x69 | 0x69 | 1 | 0xC8 | 0x69 | 0 | C8 | 69 | 192 | 192 | 11000000 | 11000000 | * | *
 |  |  | 0x4C | 0xCC | 1 | 4C | CC | 64 | 64 | 1000000 | 1000000 | * | *
 |  |  | 0x48 | 0xC8 | 1 | 48 | C8 | 64 | 64 | 1000000 | 1000000 | * | *
 |  |  | 0x3D | 0x4C | 1 | 3D | 4C | 48 | 48 | 110000 | 110000 | 51 | 49 | 3 | 1
 |  |  | 0x39 | 0x48 | 1 | 39 | 48 | 48 | 48 | 110000 | 110000 | * | *
 |  |  | 0x3D | 0x3D | 1 | 3D | 3D | 48 | 16 | 110000 | 10000 | * | *
 |  |  | 0x39 | 0x39 | 1 | 39 | 39 | 48 | 16 | 110000 | 10000 | * | *
 |  |  | 0x3D | 0x1D | 0 | 3D | 1D | 48 | 48 | 110000 | 110000 | 51 | 48 | 3 | 0
 |  |  | 0x39 | 0x19 | 0 | 39 | 19 | 48 | 48 | 110000 | 110000 | * | *
 |  |  | 0x3D | 0x3D | 1 | 3D | 3D | 48 | 0 | 110000 |  | * | *
 |  |  | 0x39 | 0x39 | 1 | 39 | 39 | 48 | 0 | 110000 |  | * | *
 |  |  | 0x2D | 0x0D | 1 | 2D | 0D | 32 | 48 | 100000 | 110000 | 32 | 55 |  | 7
 |  |  | 0x29 | 0x09 | 1 | 29 | 09 | 32 | 48 | 100000 | 110000 | * | *
 |  |  | 0x0D | 0x3D | 0 | 0D | 3D | 0 | 112 |  | 1110000 | * | *
 |  |  | 0x09 | 0x39 | 0 | 09 | 39 | 0 | 112 |  | 1110000 | * | *
 |  |  | 0xCC | 0x7D | 0 | CC | 7D | 192 | 192 | 11000000 | 11000000 | 196 | 196 | Ä | Ä
 |  |  | 0xC8 | 0x79 | 0 | C8 | 79 | 192 | 192 | 11000000 | 11000000 | * | *
 |  |  | 0x4C | 0xCC | 1 | 4C | CC | 64 | 64 | 1000000 | 1000000 | * | *
 |  |  | 0x48 | 0xC8 | 1 | 48 | C8 | 64 | 64 | 1000000 | 1000000 | * | *
 |  |  | 0x3D | 0x4C | 1 | 3D | 4C | 48 | 48 | 110000 | 110000 | 51 | 49 | 3 | 1
 |  |  | 0x39 | 0x48 | 1 | 39 | 48 | 48 | 48 | 110000 | 110000 | * | *
 |  |  | 0x3D | 0x3D | 1 | 3D | 3D | 48 | 16 | 110000 | 10000 | * | *
 |  |  | 0x39 | 0x39 | 1 | 39 | 39 | 48 | 16 | 110000 | 10000 | * | *
 |  |  | 0x3D | 0x1D | 0 | 3D | 1D | 48 | 48 | 110000 | 110000 | 52 | 48 | 4 | 0
 |  |  | 0x39 | 0x19 | 0 | 39 | 19 | 48 | 48 | 110000 | 110000 | * | *
 |  |  | 0x4D | 0x3D | 1 | 4D | 3D | 64 | 0 | 1000000 |  | * | *
 |  |  | 0x49 | 0x39 | 1 | 49 | 39 | 64 | 0 | 1000000 |  | * | *
 |  |  | 0x2D | 0x0D | 1 | 2D | 0D | 32 | 48 | 100000 | 110000 | 32 | 56 |  | 8
 |  |  | 0x29 | 0x09 | 1 | 29 | 09 | 32 | 48 | 100000 | 110000 | * | *
 |  |  | 0x0D | 0x3D | 0 | 0D | 3D | 0 | 128 |  | 10000000 | * | *
 |  |  | 0x09 | 0x39 | 0 | 09 | 39 | 0 | 128 |  | 10000000 | * | *
 |  |  | 0xCC | 0x8D | 0 | CC | 8D | 192 | 192 | 11000000 | 11000000 | 196 | 196 | Ä | Ä
 |  |  | 0xC8 | 0x89 | 0 | C8 | 89 | 192 | 192 | 11000000 | 11000000 | * | *
 |  |  | 0x4C | 0xCC | 1 | 4C | CC | 64 | 64 | 1000000 | 1000000 | * | *
 |  |  | 0x48 | 0xC8 | 1 | 48 | C8 | 64 | 64 | 1000000 | 1000000 | * | *
 |  |  | 0x3D | 0x4C | 1 | 3D | 4C | 48 | 48 | 110000 | 110000 | 51 | 49 | 3 | 1
 |  |  | 0x39 | 0x48 | 1 | 39 | 48 | 48 | 48 | 110000 | 110000 | * | *
 |  |  | 0x3D | 0x3D | 1 | 3D | 3D | 48 | 16 | 110000 | 10000 | * | *
 |  |  | 0x39 | 0x39 | 1 | 39 | 39 | 48 | 16 | 110000 | 10000 | * | *
 |  |  | 0x3D | 0x1D | 0 | 3D | 1D | 48 | 48 | 110000 | 110000 | 53 | 48 | 5 | 0
 |  |  | 0x39 | 0x19 | 0 | 39 | 19 | 48 | 48 | 110000 | 110000 | * | *
 |  |  | 0x5D | 0x3D | 1 | 5D | 3D | 80 | 0 | 1010000 |  | * | *
 |  |  | 0x59 | 0x39 | 1 | 59 | 39 | 80 | 0 | 1010000 |  | * | *
 |  |  | 0x2D | 0x0D | 0 | 2D | 0D | 32 | 48 | 100000 | 110000 | 32 | 57 |  | 9
 |  |  | 0x29 | 0x09 | 0 | 29 | 09 | 32 | 48 | 100000 | 110000 | * | *
 |  |  | 0x0D | 0x3D | 0 | 0D | 3D | 0 | 144 |  | 10010000 | * | *
 |  |  | 0x09 | 0x39 | 0 | 09 | 39 | 0 | 144 |  | 10010000 | * | *
 |  |  | 0xCC | 0x9D | 0 | CC | 9D | 192 | 192 | 11000000 | 11000000 | 196 | 196 | Ä | Ä
 |  |  | 0xC8 | 0x99 | 0 | C8 | 99 | 192 | 192 | 11000000 | 11000000 | * | *
 |  |  | 0x4C | 0xCC | 1 | 4C | CC | 64 | 64 | 1000000 | 1000000 | * | *
 |  |  | 0x48 | 0xC8 | 1 | 48 | C8 | 64 | 64 | 1000000 | 1000000 | * | *
 |  |  | 0x3D | 0x4C | 1 | 3D | 4C | 48 | 48 | 110000 | 110000 | 51 | 49 | 3 | 1
 |  |  | 0x39 | 0x48 | 1 | 39 | 48 | 48 | 48 | 110000 | 110000 | * | *
 |  |  | 0x3D | 0x3D | 1 | 3D | 3D | 48 | 16 | 110000 | 10000 | * | *
 |  |  | 0x39 | 0x39 | 1 | 39 | 39 | 48 | 16 | 110000 | 10000 | * | *
 |  |  | 0x3D | 0x1D | 0 | 3D | 1D | 48 | 48 | 110000 | 110000 | 54 | 49 | 6 | 1
 |  |  | 0x39 | 0x19 | 0 | 39 | 19 | 48 | 48 | 110000 | 110000 | * | *
 |  |  | 0x6D | 0x3D | 1 | 6D | 3D | 96 | 16 | 1100000 | 10000 | * | *
 |  |  | 0x69 | 0x39 | 1 | 69 | 39 | 96 | 16 | 1100000 | 10000 | * | *
 |  |  | 0x2D | 0x1D | 0 | 2D | 1D | 32 | 48 | 100000 | 110000 | 32 | 48 |  | 0
 |  |  | 0x29 | 0x19 | 0 | 29 | 19 | 32 | 48 | 100000 | 110000 | * | *
 |  |  | 0x0D | 0x3D | 0 | 0D | 3D | 0 | 0 |  |  | * | *
 |  |  | 0x09 | 0x39 | 0 | 09 | 39 | 0 | 0 |  |  | * | *
 |  |  | 0xCC | 0x0D | 1 | CC | 0D | 192 | 192 | 11000000 | 11000000 | 196 | 196 | Ä | Ä
 |  |  | 0xC8 | 0x09 | 1 | C8 | 09 | 192 | 192 | 11000000 | 11000000 | * | *
 |  |  | 0x4C | 0xCC | 1 | 4C | CC | 64 | 64 | 1000000 | 1000000 | * | *
 |  |  | 0x48 | 0xC8 | 1 | 48 | C8 | 64 | 64 | 1000000 | 1000000 | * | *
 |  |  | 0x3D | 0x4C | 1 | 3D | 4C | 48 | 48 | 110000 | 110000 | 51 | 49 | 3 | 1
 |  |  | 0x39 | 0x48 | 1 | 39 | 48 | 48 | 48 | 110000 | 110000 | * | *
 |  |  | 0x3D | 0x3D | 1 | 3D | 3D | 48 | 16 | 110000 | 10000 | * | *
 |  |  | 0x39 | 0x39 | 1 | 39 | 39 | 48 | 16 | 110000 | 10000 | * | *
 |  |  | 0x3D | 0x1D | 0 | 3D | 1D | 48 | 48 | 110000 | 110000 | 55 | 49 | 7 | 1
 |  |  | 0x39 | 0x19 | 0 | 39 | 19 | 48 | 48 | 110000 | 110000 | * | *
 |  |  | 0x7D | 0x3D | 1 | 7D | 3D | 112 | 16 | 1110000 | 10000 | * | *
 |  |  | 0x79 | 0x39 | 1 | 79 | 39 | 112 | 16 | 1110000 | 10000 | * | *
 |  |  | 0x2D | 0x1D | 0 | 2D | 1D | 32 | 48 | 100000 | 110000 | 32 | 49 |  | 1
 |  |  | 0x29 | 0x19 | 0 | 29 | 19 | 32 | 48 | 100000 | 110000 | * | *
 |  |  | 0x0D | 0x3D | 0 | 0D | 3D | 0 | 16 |  | 10000 | * | *
 |  |  | 0x09 | 0x39 | 0 | 09 | 39 | 0 | 16 |  | 10000 | * | *
 |  |  | 0xCC | 0x1D | 0 | CC | 1D | 192 | 192 | 11000000 | 11000000 | 196 | 196 | Ä | Ä
 |  |  | 0xC8 | 0x19 | 0 | C8 | 19 | 192 | 192 | 11000000 | 11000000 | * | *
 |  |  | 0x4C | 0xCC | 1 | 4C | CC | 64 | 64 | 1000000 | 1000000 | * | *
 |  |  | 0x48 | 0xC8 | 1 | 48 | C8 | 64 | 64 | 1000000 | 1000000 | * | *
 |  |  | 0x3D | 0x4C | 1 | 3D | 4C | 48 | 48 | 110000 | 110000 | 51 | 49 | 3 | 1
 |  |  | 0x39 | 0x48 | 1 | 39 | 48 | 48 | 48 | 110000 | 110000 | * | *
 |  |  | 0x3D | 0x3D | 1 | 3D | 3D | 48 | 16 | 110000 | 10000 | * | *
 |  |  | 0x39 | 0x39 | 1 | 39 | 39 | 48 | 16 | 110000 | 10000 | * | *
 |  |  | 0x3D | 0x1D | 0 | 3D | 1D | 48 | 48 | 110000 | 110000 | 56 | 49 | 8 | 1
 |  |  | 0x39 | 0x19 | 0 | 39 | 19 | 48 | 48 | 110000 | 110000 | * | *
 |  |  | 0x8D | 0x3D | 1 | 8D | 3D | 128 | 16 | 10000000 | 10000 | * | *
 |  |  | 0x89 | 0x39 | 1 | 89 | 39 | 128 | 16 | 10000000 | 10000 | * | *
 |  |  | 0x2D | 0x1D | 0 | 2D | 1D | 32 | 48 | 100000 | 110000 | 32 | 50 |  | 2
 |  |  | 0x29 | 0x19 | 0 | 29 | 19 | 32 | 48 | 100000 | 110000 | * | *
 |  |  | 0x0D | 0x3D | 0 | 0D | 3D | 0 | 32 |  | 100000 | * | *
 |  |  | 0x09 | 0x39 | 0 | 09 | 39 | 0 | 32 |  | 100000 | * | *
 |  |  | 0xCC | 0x2D | 0 | CC | 2D | 192 | 192 | 11000000 | 11000000 | 196 | 196 | Ä | Ä
 |  |  | 0xC8 | 0x29 | 0 | C8 | 29 | 192 | 192 | 11000000 | 11000000 | * | *
 |  |  | 0x4C | 0xCC | 1 | 4C | CC | 64 | 64 | 1000000 | 1000000 | * | *
 |  |  | 0x48 | 0xC8 | 1 | 48 | C8 | 64 | 64 | 1000000 | 1000000 | * | *
 |  |  | 0x3D | 0x4C | 1 | 3D | 4C | 48 | 48 | 110000 | 110000 | 51 | 49 | 3 | 1
 |  |  | 0x39 | 0x48 | 1 | 39 | 48 | 48 | 48 | 110000 | 110000 | * | *
 |  |  | 0x3D | 0x3D | 1 | 3D | 3D | 48 | 16 | 110000 | 10000 | * | *
 |  |  | 0x39 | 0x39 | 1 | 39 | 39 | 48 | 16 | 110000 | 10000 | * | *
 |  |  | 0x3D | 0x1D | 0 | 3D | 1D | 48 | 48 | 110000 | 110000 | 57 | 49 | 9 | 1
 |  |  | 0x39 | 0x19 | 0 | 39 | 19 | 48 | 48 | 110000 | 110000 | * | *
 |  |  | 0x9D | 0x3D | 1 | 9D | 3D | 144 | 16 | 10010000 | 10000 | * | *
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

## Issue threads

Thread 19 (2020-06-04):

I2C driver : add a unitary read operation (no previous write to send a command to slave first)

bebenlebricolo, 2020-06-04:
## Current behavior while reading data from a slave :
* Master initiates the transmission with a start condition on I2C bus
* Master transmits the slave's address + write bit (0)
* Master captures acknowledgment from the slave and writes a command to the slave on the bus
* Master checks for Acknowledgment and sends a Start condition (repeated start) to operate the transition to read mode
* Master goes to read mode and generates the clock signal for the slave to write on the bus
* Master receives the data byte and issue a NACK/ACK, and proceeds until finishing the read transaction.

This is an issue when reading data from some - very simple - devices such as I2C I/O port expanders such as PCF8574T does not support command handling. In those cases, the read operation on its own is sufficient and data could be read directly.
* Implement an i2c_atomic_read() (a bit misleading) or i2c_direct_read(...) function to handle those kinds of operations

Closed 2021-05-16.

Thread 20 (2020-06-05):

I2C driver : add a function to retrieve last transaction result

bebenlebricolo, 2020-06-05:
When a transaction is performed (in master **and** slave mode), internal state is set to I2C_STATE_READY once the transaction completes.

However, we'll never know if that transaction went fine, maybe it has stopped because the device could not identify any slave, so there could be many reasons why a transaction would stop/complete.
For instance, (non-exhaustive list), those reasons may be implemented :
* I2C_TRANSACTION_COMPLETED_FINE (everything went fine)
* I2C_TRANSACTION_COMPLETED_NO_SLAVE_FOUND (target slave did not respond, master mode only)
* I2C_TRANSACTION_COMPLETED_MAX_RETRIES_HIT (too much nack sent/received)

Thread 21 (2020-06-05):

LCD Screen proper driver implementation

bebenlebricolo, 2020-06-05:
Implement the HD44780 / PCF8574 couple driver to be able to display useful data on a screen.

bebenlebricolo, 2021-02-10:
Closed with PR #28

Closed 2021-02-10.

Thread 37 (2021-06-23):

Implement thermistor driver

bebenlebricolo, 2021-06-23:
A proper thermistor driver is required for thermal management to handle properly temperature readings and actuation.

Closed 2021-06-23.

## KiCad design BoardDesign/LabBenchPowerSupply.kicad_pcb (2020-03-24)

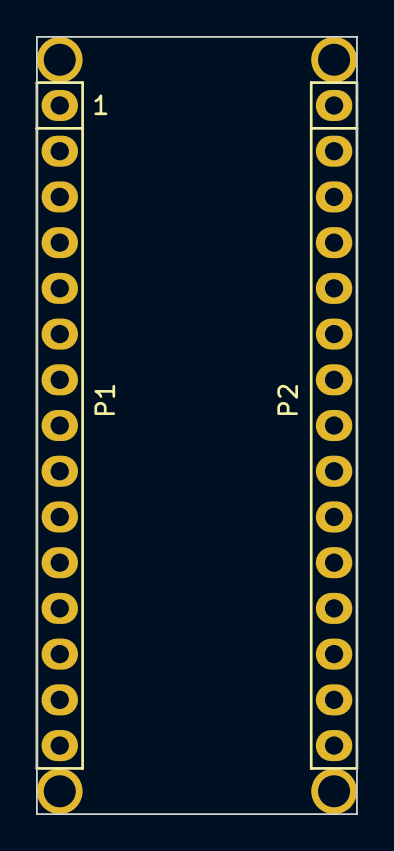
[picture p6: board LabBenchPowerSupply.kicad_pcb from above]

Board: 2 copper layers, 17.8 x 43.2 mm, 6 parts (0 on the bottom side), 2 nets, no tracks yet.

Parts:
P1: Digital; Socket_Strip_Arduino_1x15
P2: Analog; Socket_Strip_Arduino_1x15
P3, P4, P5, P6: CONN_01X01; 1pin_Nano

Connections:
/Reset: P1.3, P2.3
GND: P1.4, P2.2

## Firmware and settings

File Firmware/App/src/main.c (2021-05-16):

/*

------------------
@<FreeMyCode>
FreeMyCode version : 1.0 RC alpha
    Author : bebenlebricolo
    License : 
        name : GPLv3
        url : https://www.gnu.org/licenses/quick-guide-gplv3.html
    Date : 12/02/2021
    Project : LabBenchPowerSupply
    Description : The Lab Bench Power Supply provides a simple design based around an Arduino Nano board to convert AC main voltage into
 smaller ones, ranging from 0V to 16V, with voltage and current regulations
<FreeMyCode>@
------------------

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
You should have received a copy of the GNU General Public License
along with this program.  If not, see <https://www.gnu.org/licenses/>.
*/

#include "adc.h"
#include "timer_8_bit.h"
#include "timer_8_bit_async.h"
#include "timer_16_bit.h"
#include "HD44780_lcd.h"
#include "timebase.h"
#include "i2c.h"

#include "driver_setup.h"
#include "module_setup.h"

#include <stdlib.h>
#include <string.h>

#include <avr/interrupt.h>

#define MAX_MUX 5

static adc_mux_t mux_table[MAX_MUX] =
{
    ADC_MUX_ADC0,
    ADC_MUX_ADC1,
    ADC_MUX_ADC2,
    ADC_MUX_ADC3,
    ADC_MUX_ADC4,
};

static void error_handler(void);
static void bootup_sequence(void);
static driver_setup_error_t adc_register_all_channels(void);
static void adc_read_values(void);
static void print_data(void);

ISR(ADC_vect)
{
    adc_isr_handler();
}

ISR(TIMER2_COMPA_vect)
{
    timebase_interrupt_callback(0U);
}

int main(void)
{
    bootup_sequence();

    i2c_error_t i2c_err = I2C_ERROR_OK;

    while(true)
    {
        i2c_err = i2c_process(0U);
        (void) i2c_err;
        adc_read_values();
        print_data();
    }

    return 0;
}

/* ########################################################################################
   ########################## Static functions definitions ################################
   ######################################################################################## */

void adc_read_values(void)
{
    static uint8_t idx = 0;
    adc_result_t results[5];
    adc_read_raw(mux_table[idx % MAX_MUX], &results[idx]);

    idx++;
    idx %= MAX_MUX;
}

void error_handler(void)
{
    while(1)
    {
    }
}

driver_setup_error_t adc_register_all_channels(void)
{
    for (uint8_t i = 0; i < MAX_MUX ; i++)
    {
        adc_error_t err = adc_register_channel(mux_table[i]);
        if (ADC_ERROR_OK != err)
        {
            return DRIVER_SETUP_ERROR_INIT_FAILED;
        }
    }
    return DRIVER_SETUP_ERROR_OK;
}

static void bootup_sequence(void)
{

    driver_setup_error_t driver_init_error = DRIVER_SETUP_ERROR_OK;
    module_setup_error_t module_init_error = MODULE_SETUP_ERROR_OK;

    /* Set up 8 bit timer 0 as 8 bit FAST PWM generator */
    driver_init_error = driver_init_timer_0();
    if (DRIVER_SETUP_ERROR_OK != driver_init_error)
    {
        error_handler();
    }

    /* Set up 16 bit timer 1 as 10 bit FAST PWM generator */
    driver_init_error = driver_init_timer_1();
    if (DRIVER_SETUP_ERROR_OK != driver_init_error)
    {
        error_handler();
    }

    /* Set up 8 bit timer 2 as 8 bit FAST PWM generator */
    driver_init_error = driver_init_timer_2();
    if (DRIVER_SETUP_ERROR_OK != driver_init_error)
    {
        error_handler();
    }

    module_init_error = module_init_timebase();
    if (MODULE_SETUP_ERROR_OK != module_init_error)
    {
        error_handler();
    }

    driver_init_error = driver_init_adc();
    if (DRIVER_SETUP_ERROR_OK != driver_init_error)
    {
        error_handler();
    }

    driver_init_error = driver_init_i2c();
    if (DRIVER_SETUP_ERROR_OK != driver_init_error)
    {
        error_handler();
    }

    driver_init_error = driver_init_lcd();
    if (DRIVER_SETUP_ERROR_OK != driver_init_error)
    {
        error_handler();
    }

    driver_init_error = adc_register_all_channels();
    if (DRIVER_SETUP_ERROR_OK != driver_init_error)
    {
        error_handler();
    }

    adc_start();
    sei();

    /* Start both timers */
    timer_error_t timer_error = timer_8_bit_start(0);
    if (TIMER_ERROR_OK != timer_error)
    {
        error_handler();
    }
    timer_error = timer_16_bit_start(0);
    if (TIMER_ERROR_OK != timer_error)
    {
        error_handler();
    }
    timer_error = timer_8_bit_async_start(0);
    if (TIMER_ERROR_OK != timer_error)
    {
        error_handler();
    }
}

static void print_data(void)
{
    static char msg1[30] = "Hello World!";
    static char msg2[30] = "i = ";
    static uint8_t state_count = 0;
    static uint8_t iterations = 0;
    static bool move_cursor = false;

    static char iteration_string[5] = "";

    hd44780_lcd_state_t state = hd44780_lcd_get_state();
    hd44780_lcd_error_t err = HD44780_LCD_ERROR_OK;

    if (HD44780_LCD_STATE_READY != state)
    {
        err = hd44780_lcd_process();
    }
    else
    {
        switch(state_count)
        {
            case 0 :
                err = hd44780_lcd_set_display_on_off(true);
                break;
            case 1 :
                err = hd44780_lcd_move_cursor_to_coord(0,0);
                break;
            case 2 :
                err = hd44780_lcd_print(strnlen(msg1, 30U), msg1);
                break;
            case 3 :
                err = hd44780_lcd_move_cursor_to_coord(1,0);
                break;
            case 4 :
                err = hd44780_lcd_print(strnlen(msg2, 30U), msg2);
                break;
            case 5 :
                err = hd44780_lcd_set_blinking_cursor(false);
                break;
            case 6:
                err = hd44780_lcd_set_cursor_visible(false);
                break;
            case 7 :
                if (move_cursor)
                {
                    err = hd44780_lcd_move_cursor_to_coord(1, 4U);
                    move_cursor = false;
                }
                else
                {
                    itoa(iterations, iteration_string, 10U);
                    int len = strnlen(iteration_string, 5U);
                    memset(&iteration_string[len], ' ', (5U - len));
                    // Replace null-terminating characters in string
                    //for (uint8_t i = len ; i < 5U ; i++)
                    //{
                    //    if (iteration_string[i] == 0)
                    //    {
                    //        iteration_string[i] = ' ';
                    //    }
                    //}
                    err = hd44780_lcd_print(3U, iteration_string);
                    iterations++;
                    move_cursor = true;
                }
                break;

            default:
                break;
        }

        if (state_count < 7U)
        {
            state_count++;
        }
    }
    (void) err;
}

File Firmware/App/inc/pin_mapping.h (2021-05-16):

/*

------------------
@<FreeMyCode>
FreeMyCode version : 1.0 RC alpha
    Author : bebenlebricolo
    License : 
        name : GPLv3
        url : https://www.gnu.org/licenses/quick-guide-gplv3.html
    Date : 12/02/2021
    Project : LabBenchPowerSupply
    Description : The Lab Bench Power Supply provides a simple design based around an Arduino Nano board to convert AC main voltage into
 smaller ones, ranging from 0V to 16V, with voltage and current regulations
<FreeMyCode>@
------------------

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
You should have received a copy of the GNU General Public License
along with this program.  If not, see <https://www.gnu.org/licenses/>.
*/

#ifndef PIN_MAPPING_HEADER
#define PIN_MAPPING_HEADER

#include <avr/io.h>

// ####################################################################################
// ######################### Timers output compare pins  ##############################
// ####################################################################################

/* Timer 0 output compare pins */
#define OC0A_PIN_NUMBER PORTD6
#define OC0A_PORT_REG   PORTD
#define OC0A_DDR_REG    DDRD
#define OCOA_PIN_REG    PIND

#define OC0B_PIN_NUMBER PORTD5
#define OC0B_PORT_REG   PORTD
#define OC0B_DDR_REG    DDRD
#define OCOB_PIN_REG    PIND

/* Timer 1 output compare pins */
#define OC1A_PIN_NUMBER PORTB1
#define OC1A_PORT_REG   PORTB
#define OC1A_DDR_REG    DDRB
#define OC1A_PIN_REG    PINB

#define OC1B_PIN_NUMBER PORTB2
#define OC1B_PORT_REG   PORTB
#define OC1B_DDR_REG    DDRB
#define OC1B_PIN_REG    PINB

/* Timer 2 output compare pins */
#define OC2A_PIN_NUMBER PORTB3
#define OC2A_PORT_REG   PORTB
#define OC2A_DDR_REG    DDRB
#define OC2A_PIN_REG    PINB

#define OC2B_PIN_NUMBER PORTD3
#define OC2B_PORT_REG   PORTD
#define OC2B_DDR_REG    DDRD
#define OC2B_PIN_REG    PIND

// ####################################################################################
// ######################### Buttons user interface ###################################
// ####################################################################################

/* Buttons interface mapping */
#define BUTTON_PLUS_PIN_NUMBER PORTD2
#define BUTTON_PLUS_PORT_REG   PORTD
#define BUTTON_PLUS_DDR_REG    DDRD
#define BUTTON_PLUS_PIN_REG    PIND

#define BUTTON_MINUS_PIN_NUMBER PORTD3
#define BUTTON_MINUS_PORT_REG   PORTD
#define BUTTON_MINUS_DDR_REG    DDRD
#define BUTTON_MINUS_PIN_REG    PIND

#define BUTTON_VARSELECT_PIN_NUMBER PORTD4
#define BUTTON_VARSELECT_PORT_REG   PORTD
#define BUTTON_VARSELECT_DDR_REG    DDRD
#define BUTTON_VARSELECT_PIN_REG    PIND

#define BUTTON_MODE_PIN_NUMBER PORTD5
#define BUTTON_MODE_PORT_REG   PORTD
#define BUTTON_MODE_DDR_REG    DDRD
#define BUTTON_MODE_PIN_REG    PIND

// ####################################################################################
// ######################### Power mosfet pins ########################################
// ####################################################################################

/* Mosfet controls */
#define MOSFET_HIGH_SIDE_PIN_NUMBER PORTB1   // Wired to OC1A output
#define MOSFET_HIGH_SIDE_PORT_REG   PORTB
#define MOSFET_HIGH_SIDE_DDR_REG    DDRB
#define MOSFET_HIGH_SIDE_PIN_REG    PINB

#define MOSFET_LOW_SIDE_PIN_NUMBER PORTB2   // Wired to OC1B output
#define MOSFET_LOW_SIDE_PORT_REG   PORTB
#define MOSFET_LOW_SIDE_DDR_REG    DDRB
#define MOSFET_LOW_SIDE_PIN_REG    PINB

// ####################################################################################
// ######################### Fan control network ######################################
// ####################################################################################

/* Fan control network */
#define FAN_CONTROL_PIN_NUMBER PORTD6   // which is wired to OC0A output
#define FAN_CONTROL_PORT_REG   PORTD
#define FAN_CONTROL_DDR_REG    DDRD
#define FAN_CONTROL_PIN_REG    PIND

// ####################################################################################
// ############################# Analog readings ######################################
// ####################################################################################

/* Temperature probe, analogic reading */
#define TEMP_PROBE_PIN_NUMBER PORTC3
#define TEMP_PROBE_PORT_REG   PORTC
#define TEMP_PROBE_DDR_REG    DDRC
#define TEMP_PROBE_PIN_REG    PINC
#define TEMP_PROBE_ADC        ADC3

/* Voltage analogic readings */
#define SECONDARY_SMOOTHED_PIN_NUMBER PORTC2
#define SECONDARY_SMOOTHED_PORT_REG   PORTC
#define SECONDARY_SMOOTHED_DDR_REG    DDRC
#define SECONDARY_SMOOTHED_PIN_REG    PINC
#define SECONDARY_SMOOTHED_ADC        ADC2

/* Voltage analogic readings */
#define OUTVOLTAGE_SENSING_PIN_NUMBER PORTC1
#define OUTVOLTAGE_SENSING_PORT_REG   PORTC
#define OUTVOLTAGE_SENSING_DDR_REG    DDRC
#define OUTVOLTAGE_SENSING_PIN_REG    PINC
#define OUTVOLTAGE_SENSING_ADC        ADC1
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

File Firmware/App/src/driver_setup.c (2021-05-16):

/*

------------------
@<FreeMyCode>
FreeMyCode version : 1.0 RC alpha
    Author : bebenlebricolo
    License : 
        name : GPLv3
        url : https://www.gnu.org/licenses/quick-guide-gplv3.html
    Date : 12/02/2021
    Project : LabBenchPowerSupply
    Description : The Lab Bench Power Supply provides a simple design based around an Arduino Nano board to convert AC main voltage into
 smaller ones, ranging from 0V to 16V, with voltage and current regulations
<FreeMyCode>@
------------------

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
You should have received a copy of the GNU General Public License
along with this program.  If not, see <https://www.gnu.org/licenses/>.
*/

#include "driver_setup.h"

#include <avr/io.h>
#include "adc.h"
#include "timer_8_bit.h"
#include "timer_8_bit_async.h"
#include "timer_16_bit.h"
#include "i2c.h"
#include "HD44780_lcd.h"

#include "pin_mapping.h"
driver_setup_error_t driver_init_adc(void)
{
    adc_config_hal_t config;
    adc_config_hal_get_default(&config);
    config.prescaler = ADC_PRESCALER_64;
    config.ref = ADC_VOLTAGE_REF_AVCC;
    config.running_mode = ADC_RUNNING_MODE_SINGLE_SHOT;
    config.supply_voltage_mv = 5000;
    config.using_interrupt = true;


    adc_error_t init_err = adc_base_init(&config);
    if (ADC_ERROR_OK != init_err)
    {
        return DRIVER_SETUP_ERROR_INIT_FAILED;
    }
    return DRIVER_SETUP_ERROR_OK;
}


driver_setup_error_t driver_init_timer_0(void)
{
    timer_8_bit_config_t config;
    timer_error_t local_error;
    {
        local_error = timer_8_bit_get_default_config(&config);
        if (TIMER_ERROR_OK != local_error)
        {
            return DRIVER_SETUP_ERROR_INIT_FAILED;
        }
    }

    /* Configuring handle */
    config.handle.OCRA = &OCR0A;
    config.handle.OCRB = &OCR0B;
    config.handle.TCCRA = &TCCR0A;
    config.handle.TCCRB = &TCCR0B;
    config.handle.TCNT = &TCNT0;
    config.handle.TIFR = &TIFR0;
    config.handle.TIMSK = &TIMSK0;

	/* Enable OC0A and OC0B as outputs */
    OC0A_DDR_REG |= (1 << OC0A_PIN_NUMBER);
    OC0B_DDR_REG |= (1 << OC0B_PIN_NUMBER);

    /* Set original port state of OC0A/OC0B pins before any OCRx overrides them */
    /* This is done in opposing polarities to respect mosfet push-pull driver pair starting point*/
    OC0A_PORT_REG |= (1 << OC0A_PIN_NUMBER);
    OC0B_PORT_REG &= ~(1 << OC0B_PIN_NUMBER);

    /* Configuring timer */
    /* F_CPU = 16'000'000 Hz ; F_TIMER0 2'000'000 Hz*/
    /* 8-bit wide -> 256 values => F_PWM_0 = 7812 Hz*/
    config.timing_config.prescaler = TIMER8BIT_CLK_PRESCALER_8;
    config.timing_config.waveform_mode = TIMER8BIT_WG_PWM_FAST_FULL_RANGE;
    /* Invert OC0x behavior to provide a correct PWM for a push-pull driver pair */
    config.timing_config.comp_match_a = TIMER8BIT_CMOD_CLEAR_OCnX;
    config.timing_config.comp_match_b = TIMER8BIT_CMOD_SET_OCnX;
    /* Duty cycle : 39 % */
    config.timing_config.ocra_val = 99;
    config.timing_config.ocrb_val = 99;

    {
        local_error = timer_8_bit_init(0, &config);
        if (TIMER_ERROR_OK != local_error)
        {
            return DRIVER_SETUP_ERROR_INIT_FAILED;
        }
    }
    return DRIVER_SETUP_ERROR_OK;
}

driver_setup_error_t driver_init_timer_1(void)
{
    timer_16_bit_config_t config;
    timer_error_t local_error;
    {
        local_error = timer_16_bit_get_default_config(&config);
        if (TIMER_ERROR_OK != local_error)
        {
            return DRIVER_SETUP_ERROR_INIT_FAILED;
        }
    }

    /* Configuring handle */
    config.handle.OCRA_H = &OCR1AH;
    config.handle.OCRA_L = &OCR1AL;
    config.handle.OCRB_H = &OCR1BH;
    config.handle.OCRB_L = &OCR1BL;
    config.handle.TCCRA = &TCCR1A;
    config.handle.TCCRB = &TCCR1B;
    config.handle.TCCRC = &TCCR1C;
    config.handle.TCNT_H = &TCNT1H;
    config.handle.TCNT_L = &TCNT1L;
    config.handle.TIFR = &TIFR1;
    config.handle.TIMSK = &TIMSK1;
    config.handle.ICR_H = &ICR1H;
    config.handle.ICR_L = &ICR1L;

	/* Enable OC0A and OC0B as outputs */
    /* PD6 = OC0A on arduino nano */
    /* PD5 = OC0B on arduino nano */
    OC1A_DDR_REG |= (1 << OC1A_PIN_NUMBER);
    OC1B_DDR_REG |= (1 << OC1B_PIN_NUMBER);

    /* Set original port state of OC0A/OC0B pins before any OCRx overrides them */
    /* This is done in opposing polarities to respect mosfet push-pull driver pair starting point*/
    OC1A_PORT_REG |= (1 << OC1A_PIN_NUMBER);    // Pulled to Vcc (low side of mosfet driver pulls mosfet's gate to ground)
    OC1B_PORT_REG &= ~(1 << OC1B_PIN_NUMBER);   // Pulled to ground (high side of mosfet driver is depleted)

    /* Configuring timer */
    /* F_CPU = 16'000'000 Hz ; F_TIMER0 2'000'000 Hz*/
    /* 10-bit wide -> 1024 values => F_PWM_1 = 1953 Hz*/
    config.timing_config.prescaler = TIMER16BIT_CLK_PRESCALER_8;
    config.timing_config.waveform_mode = TIMER16BIT_WG_PWM_FAST_10_bit_FULL_RANGE;
    /* Invert OC0x behavior to provide a correct PWM for a push-pull driver pair */
    config.timing_config.comp_match_a = TIMER16BIT_CMOD_CLEAR_OCnX;
    config.timing_config.comp_match_b = TIMER16BIT_CMOD_SET_OCnX;
    /* Duty cycle : 50 % */
    config.timing_config.ocra_val = 512;
    config.timing_config.ocrb_val = 512;

    {
        local_error = timer_16_bit_init(0, &config);
        if (TIMER_ERROR_OK != local_error)
        {
            return DRIVER_SETUP_ERROR_INIT_FAILED;
        }
    }
    return DRIVER_SETUP_ERROR_OK;
}
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

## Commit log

2020-03-24 Initial commit, hardware design only
    [Cooling.sch, LabBenchPowerSupply.kicad_pcb, LabBenchPowerSupply.sch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]
2020-03-24 Modified repo structure
    [Cooling.sch, LabBenchPowerSupply.kicad_pcb, LabBenchPowerSupply.sch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]
2020-03-24 Added fans and transformer in RequiredComponents list
    [RequiredComponents.ods]
2020-03-25 Added fans to required components list
    [RequiredComponents.ods]
2020-03-25 Modified circuitry to only have one buck converter with an antilatchup driver circuitry
    [Cooling.sch, LabBenchPowerSupply.sch]
2020-03-25 Added links in Required components list + modified circuitry
    [LabBenchPowerSupply.sch, RequiredComponents.ods]
2020-03-26 Rectified wrong rectifier diode bridge wiring
    [LabBenchPowerSupply.sch]
2020-03-26 Added reference to 1mm copper wire
    [RequiredComponents.ods]
2020-03-28 Added more references in RequiredComponents
    * power mosfet and heatsinks
    * Many declinations of heatsinks
    * Many declinations of fans
    [RequiredComponents.ods]
2020-03-28 Added simulations for a Mosfet driver circuit based on bjt
2020-03-29 Modified Mosfet driver circuit
    * Changed push-pull configuration :
    * Two channels instead of one, mainly because
    the two output transistors may be burning one another when
    input is left unconnected
    * Still 4 transistors, but this time 3 NPN and one PNP
    * 2 NPNs for the low side, one driving and the other one preventing
    high side line to conflict with low side line (whenever both lines
    are activated, this protection NPN will pull the base of the NPN of
    high side channel, preventing both lines to be active at the same
    time
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2020-03-29 Modified labels & driver circuitry
    [Cooling.sch, LabBenchPowerSupply.sch, MountBase.stl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]
2020-03-29 Added missing parts + reordering
    [RequiredComponents.ods]
2020-03-31 Improved design of board mounts
    [MountBase.stl, Proto1_BoardMount.FCStd]
2020-03-31 Adapted divider bridges to max input 33V
    [LabBenchPowerSupply.sch]
2020-03-31 Added more mechanical designs
    [MountBaseSlim.stl, MountBaseThick.stl, Proto1_BoardMount.FCStd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]
2020-04-01 Added user-interface buttons wiring
    [Cooling.sch, LabBenchPowerSupply.sch, UserInterface.sch]
2020-04-02 Adapted schematic to parallel transformer's secondary
    [LabBenchPowerSupply.sch]
2020-04-02 Added sources for P Mosfets in RequiredComponents
    [RequiredComponents.ods]
2020-04-03 Added a mounting sticking base for all racks
    [LabBenchPowerSupply.sch, MountBaseThick.stl, Proto1_BoardMount.FCStd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]
2020-04-05 First test of LCD screen on an arduino Uno
2020-04-05 Adapted thermistor divider bridge to 10k thermistor I had lying around
    [Cooling.sch, LabBenchPowerSupply.sch]
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2020-04-07 Finalised implementation of adc driver without ISR, not tested yet
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2020-04-08 Added adc register pseudo simulation feature in tests
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2020-04-08 Fixed warnings & added top-project CMakeLists.txt to compile libs and tests
    [adc_driver_tests.cpp, adc_stack.c, adc_stack_tests.cpp]
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2020-04-10 Fixed little issue on driver and implemented main.c
    [adc.c, main.c]
2020-04-12 Stabilised tests as well
    [adc.c, adc_driver_tests.cpp, adc_reg.h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]
2020-04-12 Added information to PWM pins on schematic
    [LabBenchPowerSupply.sch]
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2020-04-13 Revised a bit types declaration for timers
    [LabBenchPowerSupply.sch]
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2020-04-14 Started implementation of 8 bit timer driver without async function
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2020-04-17 Added initialisation / deinitialisation tests for timer 8 bit
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2020-04-17 Refactored timer 8 bit regular driver to match 8 bit async implementation
2020-04-20 Ported tests to timer8bit async (duplicated from timer 8 bit
2020-04-20 Added register busy test check in timer 8 bit async tests
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2020-04-21 Migrated Tests from generam Timers/Tests to individual Timers/Timer_X_bit/Tests
2020-04-21 Fixed wrong modification on timer initialisation procedure
    [main.c]
2020-04-22 Added ATmelstudio project to test timer8_bit driver with a simulator
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2020-04-23 Added pin mapping and tested timer 0 and 1
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2020-05-09 Started writing I2C interface code (no .c yet)
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2020-05-09 Partially implemented I2C Master TX/RX and Slave TX
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2020-05-09 Working on i2c write command and internal management
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2020-05-09 Manually check I2C Slave TX/RX implementations, time to move on to writting some tests
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2020-05-09 Added guard wrong device test to I2c test suite
    [i2c.c, i2c.h]
2020-05-09 Fixed mistakes within unitary accessors api tests
    [i2c.c]
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2020-05-11 Refined a bit general i2c simulated devices interface
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2020-05-13 Reworked processing order while reading / writing stuff on bus
    [i2c.h, twi_hardware_stub.c]
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2020-05-18 Added first implementation of master read ; does not work yet
    [i2c.c, twi_hardware_stub.c]
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2020-05-26 Fixed new warnings coming from transition from G++ 9.3 to G++ 10.0
    [adc.c, i2c.c, i2c.h]
2020-05-26 Repaired broken tests on read message from device test
    [twi_hardware_stub.c]
2020-05-29 Started twi slave implementation, does not work yet
    [i2c.h, twi_hardware_stub.c]
2020-05-29 Had the first transmission from an external master to twi device as slave
2020-06-02 Fully tested I2C driver, seems to work as expected!
2020-06-03 Added Readme file to explain the work done for I2C driver
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2020-06-08 Moved source file to the correct location
    [HD44780_lcd.c]
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2020-06-10 Renamed ERRORs enums from LCD drivers
2020-06-10 Prepared switching from enum/switch setup to function pointer only setup
2020-06-10 Swapped enum/switch with command sequencer direct call to function pointer
    [HD44780_lcd.c]
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2020-06-30 Reinforced documentation and modified I2C stub module
    [HD44780_lcd.c, HD44780_lcd_private.h, i2c.h]
2020-07-01 Added a lot more tests, Initialisation function test reworked
    [HD44780_lcd.c, HD44780_lcd_private.h]
2020-07-01 Fixed issue with missing 'first_pass' reset
    [HD44780_lcd.c]
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2020-07-10 Added tests to check driver behavior when I2C errors are encountered
    [HD44780_lcd.c, HD44780_lcd_private.h, i2c.h]
2020-08-12 Modified link in RequiredComponents
    [RequiredComponents.ods]
2020-08-12 Removed generic parts for prescalers and output compare mode from generic timer
2020-08-12 Added prescaler table to each of the timer drivers
2020-08-12 Added prescaler and ocra value compute parameter function in timer 8 bit driver
2020-08-12 Added generic timer functionality + adapted timer_8_bit_async code
2020-08-12 Updated timer_8_bit to use timer_generic and updated build scheme
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2020-08-12 Broke dependency between timer_8_bit_async and timer_8_bit
    [timer_8_bit_async_reg.h]
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2020-08-13 Removed unused callback from timer configurations and added timer_8_bit initialisation test through timebase_module
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2020-08-31 Modified a bit I2C driver : new I2C Busy state when twint is set to 0 when I2C driver is not processing
2020-08-31 Tried to workaround what seems to be a limitation from Simavr
    [main.c]
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2021-02-11 I2C driver partially released from optimization issues (-O0)
    [i2c.c, i2c.h]
2021-02-11 Added volatile handlers to manipulate internal data
    * This is the poor man's solution as it has the side effect to mark the
    internal_configuration[x].handle as volatile, meaning this data won't be
    optimized.
    * On another hand, this is what we need because the i2c_handle contains
    only pointer to twi hardware registers and we want to be able to
    dynamically change which register is called by who (enabling multiple
    twi hardware if any)
    [i2c.c, i2c.h]
2021-02-22 Added debugging documents
    [DébogageI2C Og O3 Lcd.ods, DébogageI2C Og O3 Lcd.xlsx]
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2021-02-22 Slowed down a bit LCD screen I2C requests to keep it working with fully optimized code
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2021-02-22 Added BUS error detection in I2C driver
    [i2c.c, i2c.h]
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2021-03-17 Fixed I2C read tests
    [i2c.c, i2c.h, twi_hardware_stub.c]
2021-03-17 Fixed I2C tests to accomodate for recent changes
    [i2c.c, i2c.h]
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2021-03-23 Added a way to specify where i2c driver shall look for config.h file
2021-03-23 Added master and slave fake I2C firmwares
    * Those 2 new fake firmwares will be helpful to test I2C driver with real
    hardware.
    * They'll handle master to slave read and write functionalities, using a
    simple pushbutton on the master side to help triggerring i2c communication
    between both devices, thus helping probing and channels tracing
    * For now, only master device is partially implemented
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2021-05-14 Removed wrong TWINT test on i2c_read function
    [i2c.c]
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2021-05-15 Stabilised master - slave communication in the 4 available modes
    [i2c.c, i2c.h, main.c]
2021-05-15 Fixed HD44780_LCD driver test fails
    [HD44780_lcd.c]
2021-05-16 Fixed tests on MSVC -> bitfield issues
    [HD44780_lcd_private.h]
2021-05-16 Fixed remaining i2c tests
    [twi_hardware_stub.c]
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2021-06-22 Fixed missing reference for adc driver into thermistor driver
